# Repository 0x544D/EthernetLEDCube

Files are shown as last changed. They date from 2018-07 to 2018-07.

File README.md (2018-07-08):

# EthernetLEDCube
This project contains the PCB design files and software of the Ethernet controlled 6x6x6 LED Cube project. The project was successfully finished within the "System-on-Chip (SOC) + ARM Lab" course of TU Berlin.

Further information about the project can be found in the doc folder.

Project member:
* Tobias Minn
* Arne Salzwedel
* Julian Gog
* Max Thonagel

# Video of the result

Ethernet controlled 6x6x6 RGB LED-Cube - uncut (https://www.youtube.com/watch?v=e2JtOskrisI "Ethernet controlled 6x6x6 RGB LED-Cube - uncut")

# Pictures

Picture of the FPGA Board and the designed LED Cube PCB:

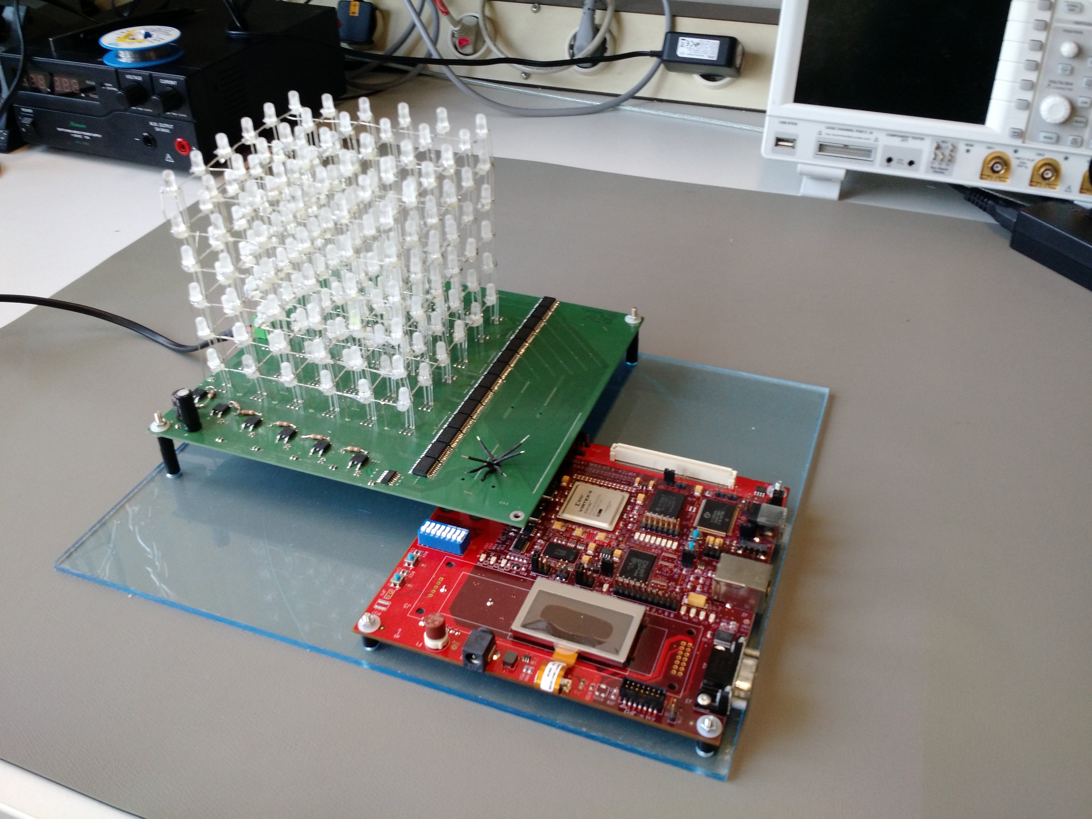
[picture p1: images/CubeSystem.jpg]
System


Animation on the Cube:
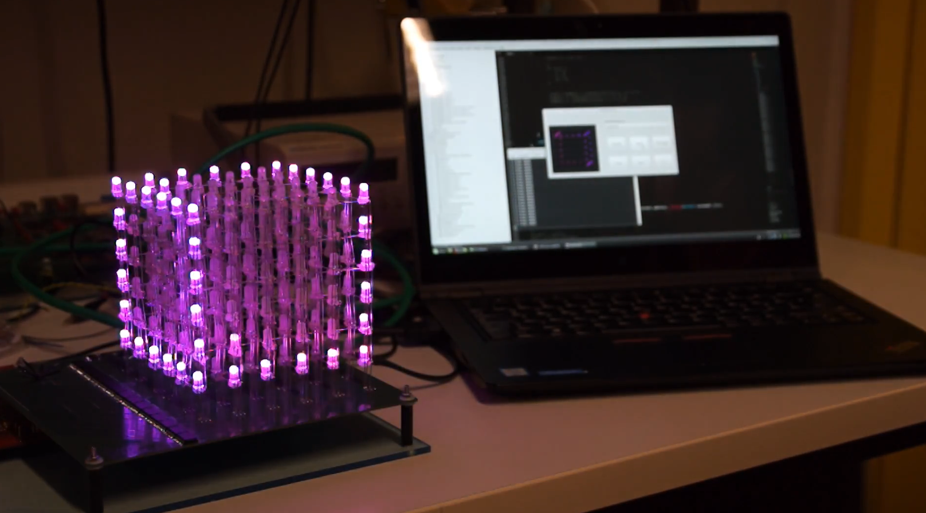
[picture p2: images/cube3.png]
Border Animation Borders


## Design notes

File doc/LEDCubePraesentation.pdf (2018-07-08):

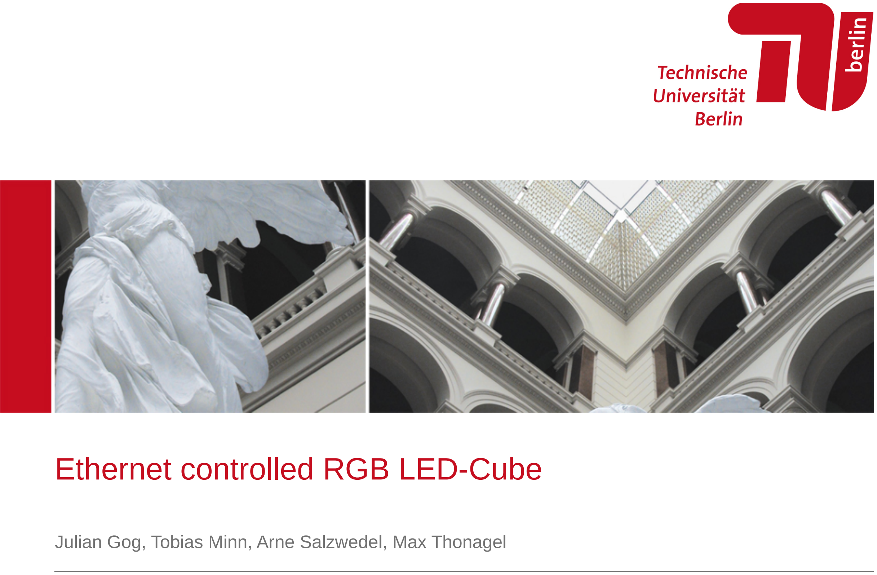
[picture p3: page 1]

# Ethernet controlled RGB LED-Cube

## Julian Gog, Tobias Minn, Arne Salzwedel, Max Thonagel

# Zielsetzung

# - 6x6x6 RGB LED-Cube

# - Ansteuerung per Ethernet

# - Verwendung von Raw-Ethernet-Frames (kein IP TCP/UDP)

Ethernet controlled RGB LED-Cube | Julian Gog, Tobias Minn, Arne Salzwedel, Max Thonagel

# Systemaufbau

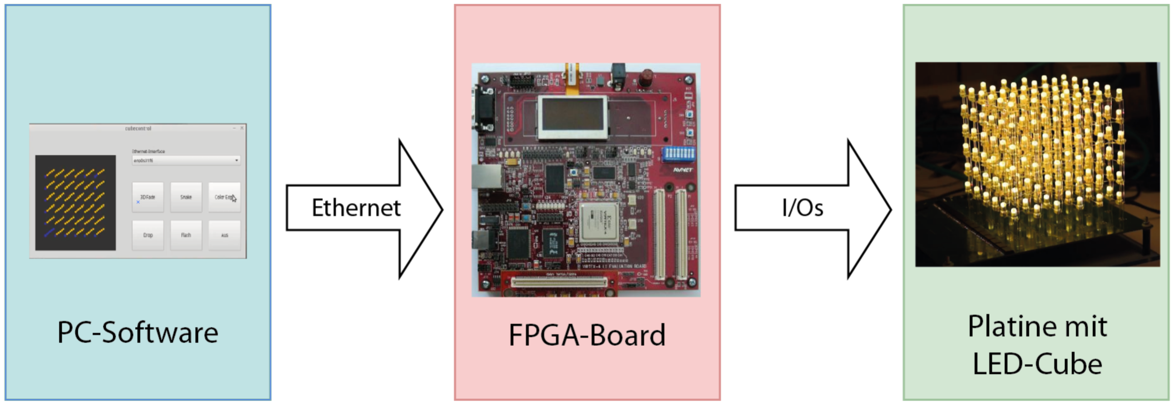
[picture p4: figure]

Bild-Quelle FPGA-Board: http://www.ue.eti.pg.gda.pl/fpgalab/spis_plytek/virtex4_av.jpg

# PC Software

# PC-Software - Aufgaben

# - Animation des Cubes mit verschieden Effekten/Mustern

# - GUI zur Interaktion mit Nutzer (Inbetriebnahme und Effekt-Auswahl)

# - Farbmischung und Dimmen

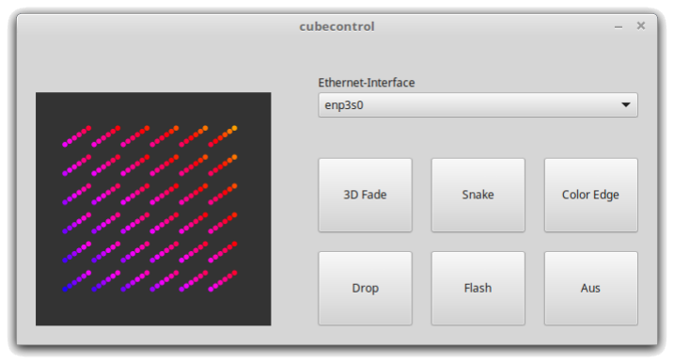
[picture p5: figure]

# durch Software-PWM

# - Codieren der Ethernet-Frames

# - Senden von Frames mit

# möglichst hoher Rate

# PC-Software - Funktionsweise

# - Bearbeitung in mehreren Threads:

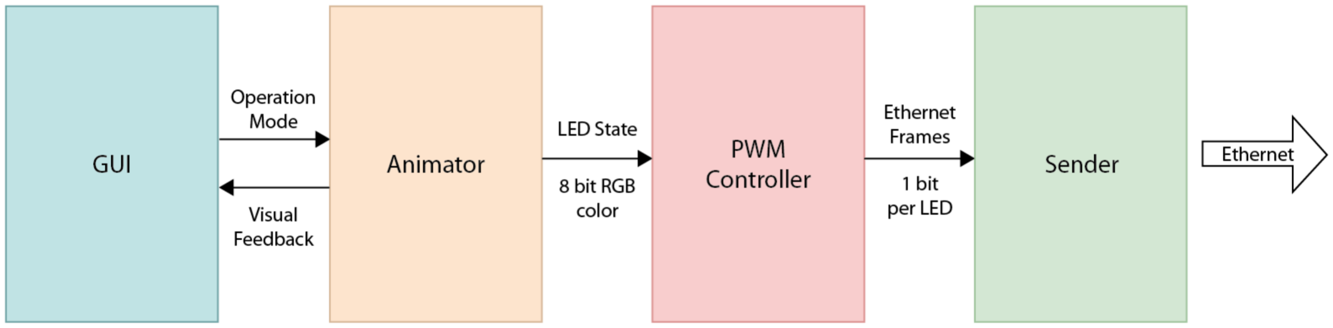
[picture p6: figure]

# System-on-Chip

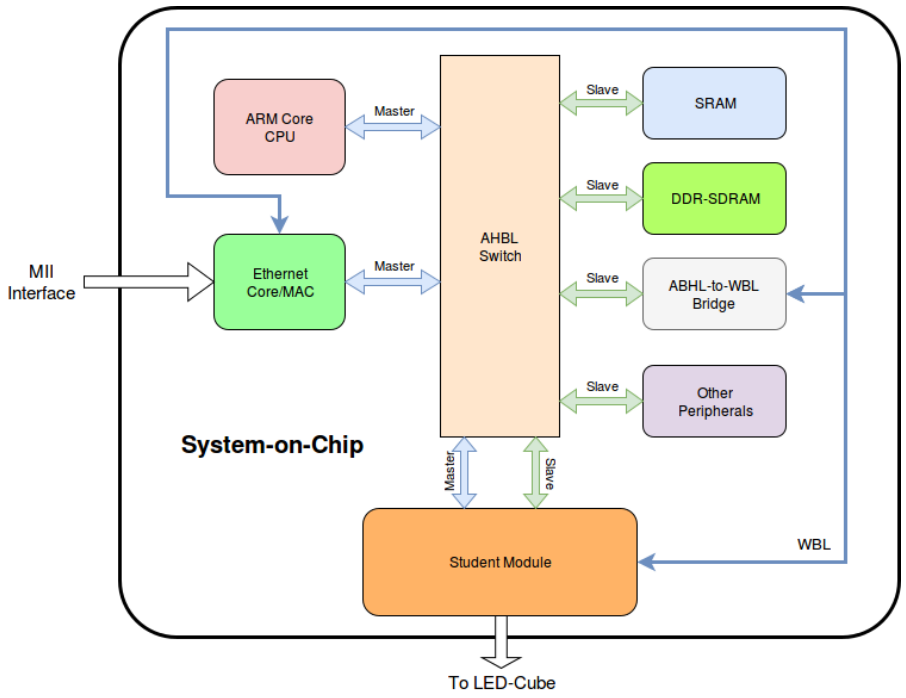
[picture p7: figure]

# Überblick

## - Standard Konfiguration des System-on-Chips des Armlabs

## - Ethernet Core/MAC wurde implementiert - Übernimmt Dekodierung des Ethernet Frames - Schreiben des Payloads in Speicher

## - Studentenmodul wurde implementiert - Enthält Ansteuerung der LED-Cube Hardware

# Ethernet Core/MAC

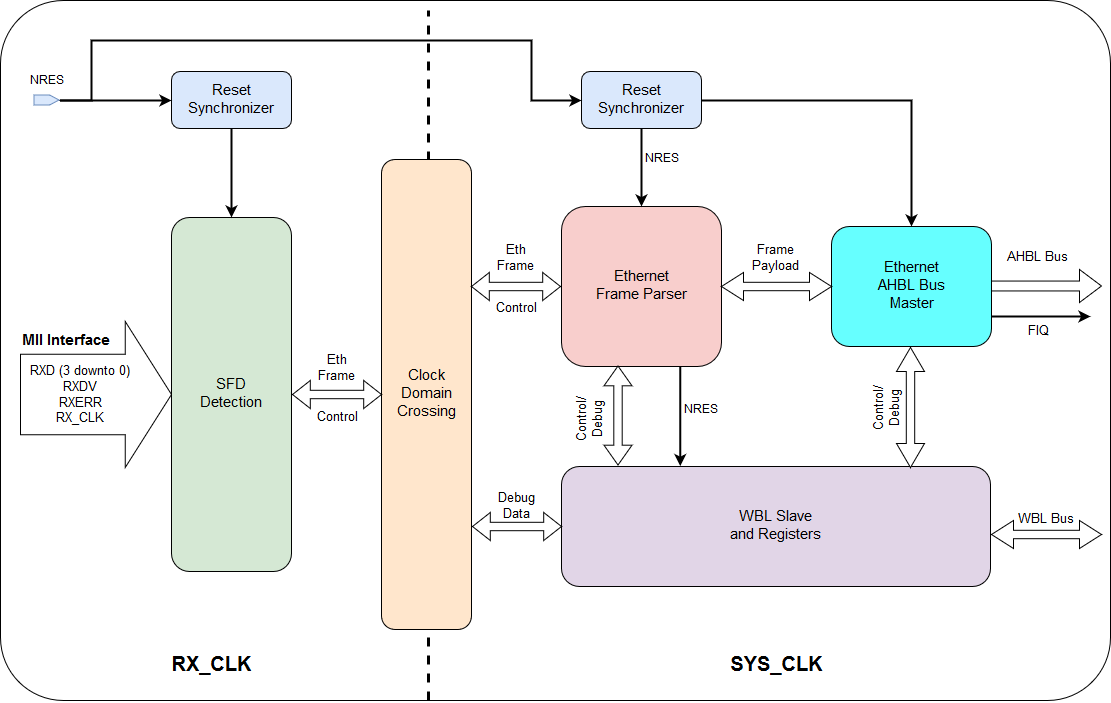
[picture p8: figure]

# SFD Erkennung

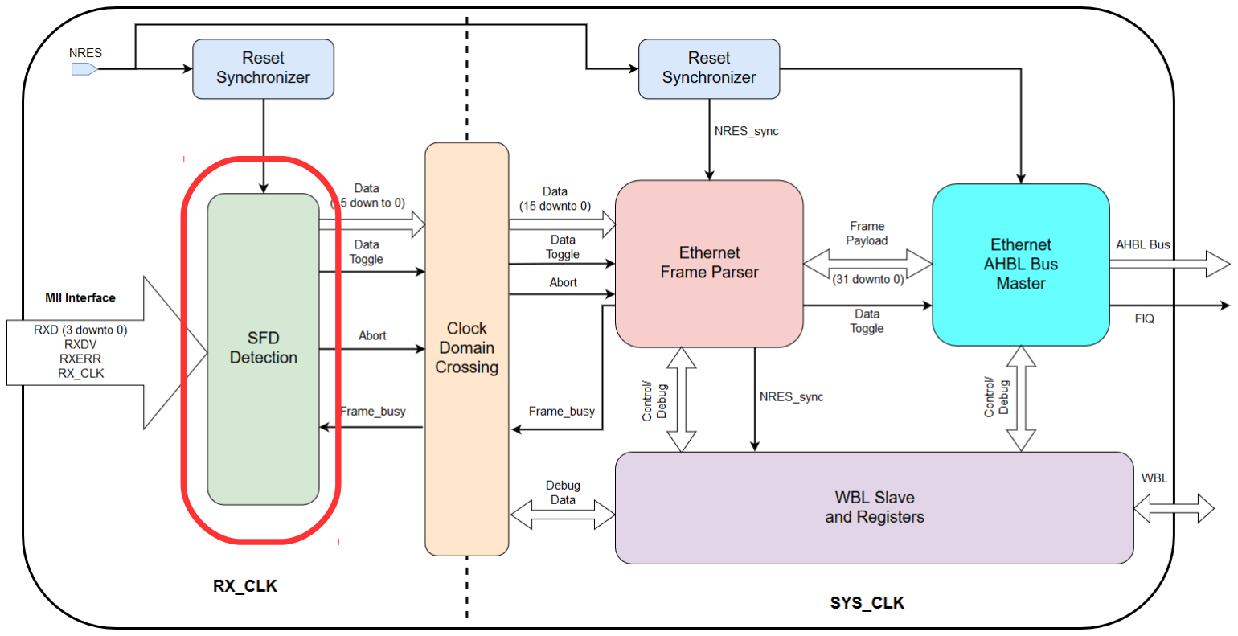
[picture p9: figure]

Preamble | Start of frame delimiter | MAC destination | MAC source | Ethertype or length | Payload | CRC
7 Bytes | 1 Byte | 6 Bytes | 6 Bytes | 2 Bytes | 46 – 1500 Bytes | 4 Bytes

## - SFD Erkennung verwirft die Preamble des Ethernet Frames bis SFD erkannt wird

## - Alle nachfolgenden Nibble werden in 16 Bit Blöcken zusammengefügt und an Parser weitergegeben

### Ethernet Frame

# Frame Parser

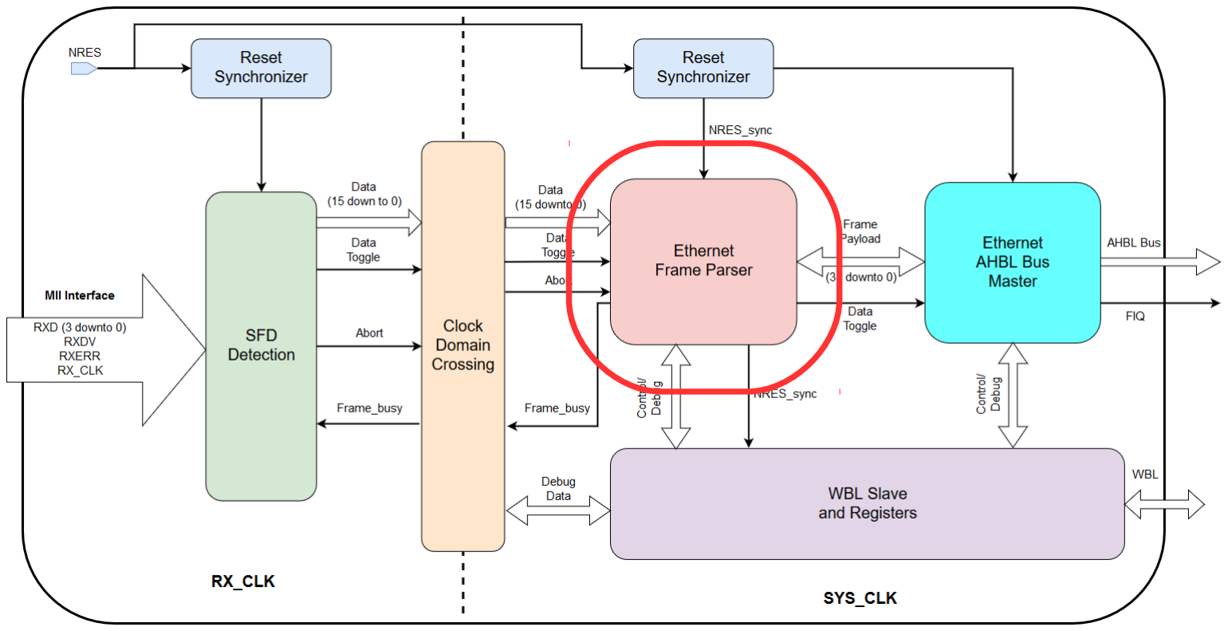
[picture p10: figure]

Preamble | Start of frame delimiter | MAC destination | MAC source | Ethertype or length | Payload | CRC
7 Bytes | 1 Byte | 6 Bytes | 6 Bytes | 2 Bytes | 46 – 1500 Bytes | 4 Bytes Ethernet Frame

## - Parser dekodiert einzelne Felder des Ethernet Frames

## - Prüft ob Ziel MAC Adresse stimmt

## - Gibt Payload und Länge an AHBL Bus Master weiter

# AHBL Bus Master

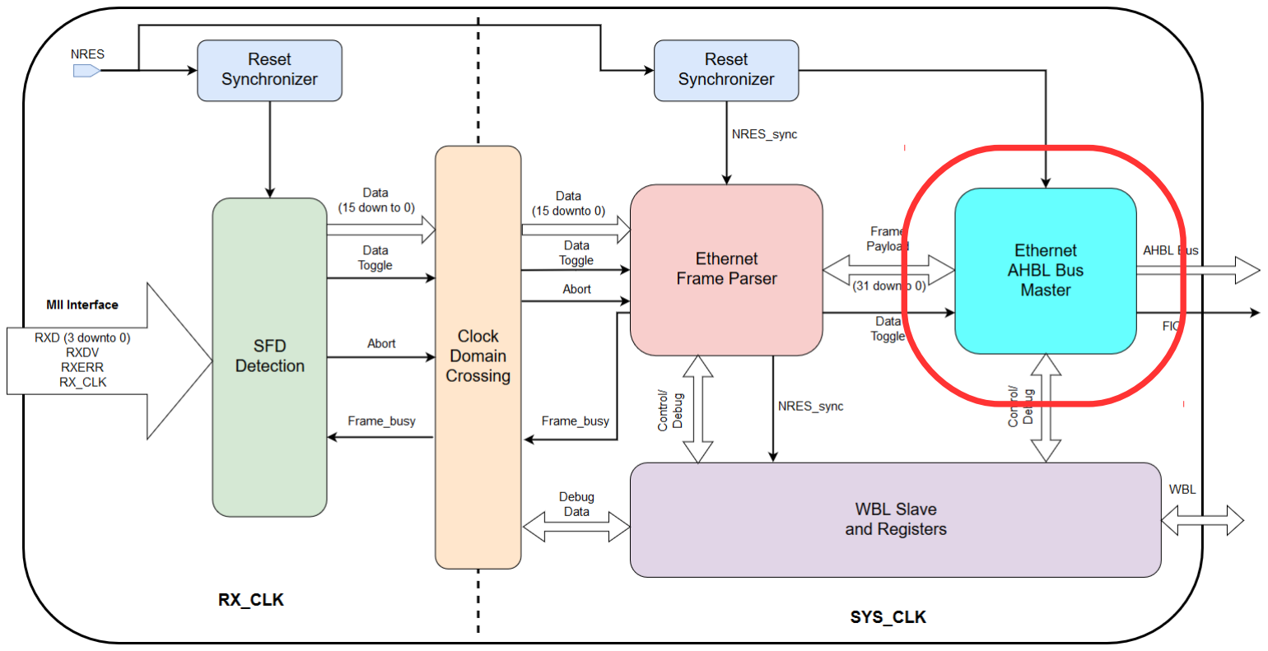
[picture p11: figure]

Preamble | Start of frame delimiter | MAC destination | MAC source | Ethertype or length | Payload | CRC
7 Bytes | 1 Byte | 6 Bytes | 6 Bytes | 2 Bytes | 46 – 1500 Bytes | 4 Bytes Ethernet Frame

## - Nimmt Daten in 32 Bit Blöcken vom Parser entgegen

## - Schreibt die ankommenden Daten an eine konfigurierbare Speicheradresse

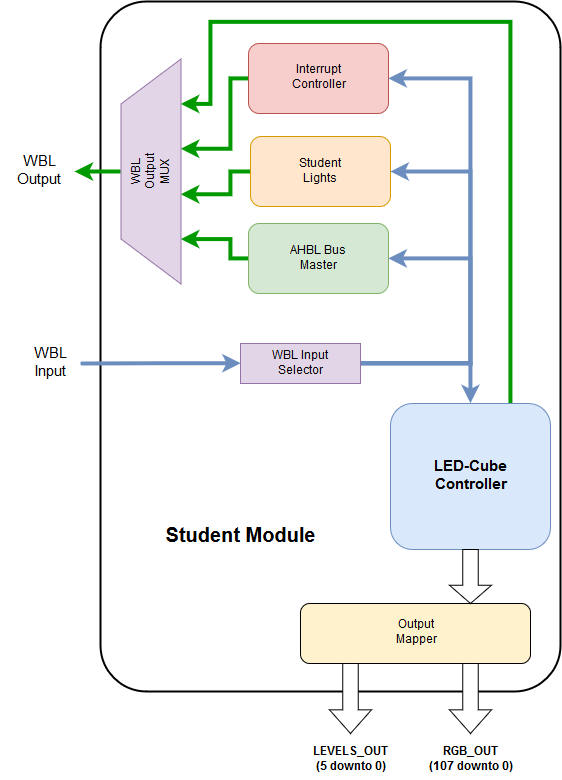
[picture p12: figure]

# LED Cube Controller

## - LED-Cube Controller übernimmt Ansteuerung des LED-Cubes – Multiplexing der LED-Ebenen – Ansteuerung der einzelnen LED Pins

## - Controller hat Register für jede LED des Cubes - Daten werden über WBL Interface in Register geschrieben - Umschalten der Ebenen auf Ausgabe Port erfolgt über MUX

# Hardware

# Hardware Features

# - 6x6x6 = 216 RGB LEDs

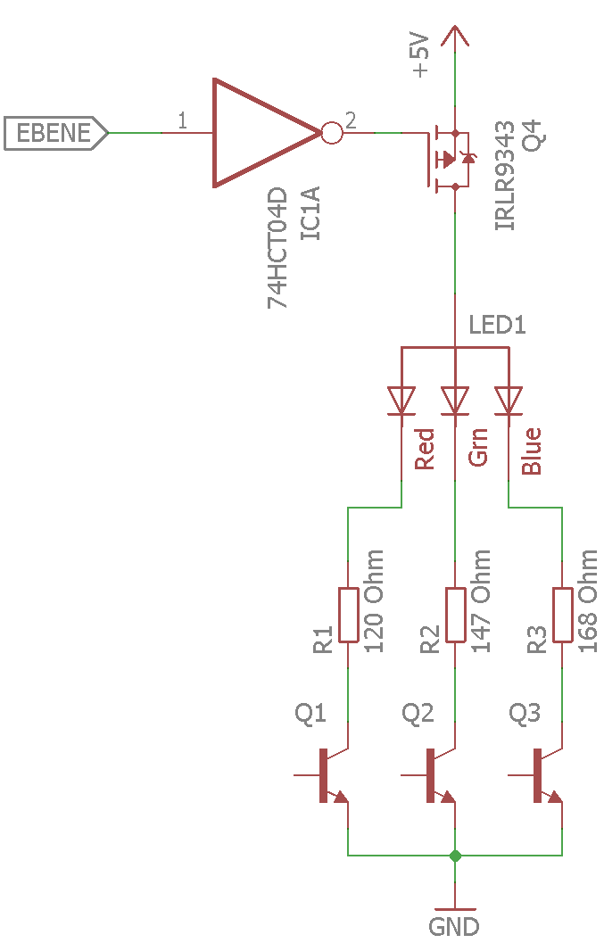
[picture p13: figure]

# - Common anode LEDs

# - Nacheinander angesteuerte

# Ebenen

# - LEDs sind nie gleichzeitig an

# - Menschliches Auge ist zu träge

# - Steuerung der LEDs via

# Darlington Arrays (ULN2803)

# - Aufbau:

…

…

…

# Demo

# Demo Video

## https://www.youtube.com/watch?v=e2JtOskrisI

# Backup Slides

# SFD Erkennung

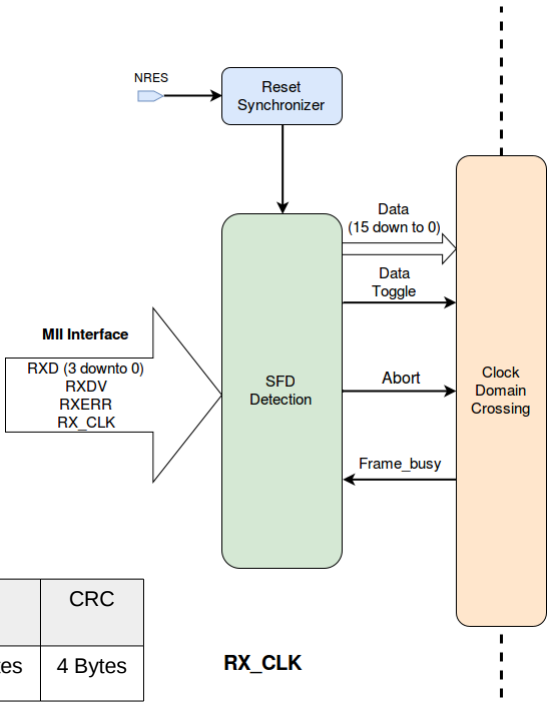
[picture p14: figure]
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

- Start of frame delimiter Erkennung nimmt Daten vom Ethernet PHY entgegen - Verwirft die Preamble des Ethernet Frames bis SFD erkannt wird - Alle nachfolgenden Nibble werden in 16 Bit Blöcken zusammengefügt - CDC von 16 Bit Blöcken in die System Clock Domain - Zusätzliche Steuersignale werden synchronisiert (Data Toggle, Abort, Frame)

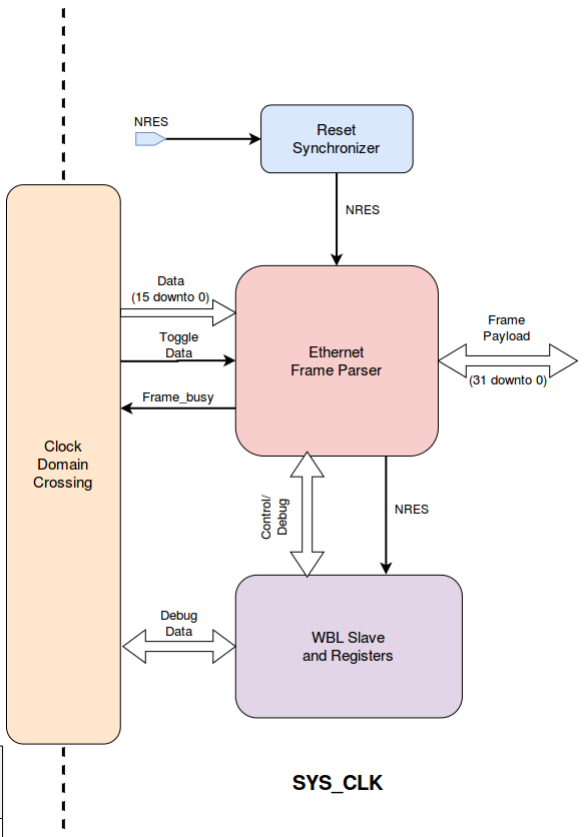
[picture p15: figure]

# Ethernet Parser

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

## - Dekodiert die ankommenden 16 Bit Blöcke

- Prüft ob ankommende Pakete für FPGA bestimmt sind,

## anhand der Ziel MAC-Adresse (konfigurierbar) - Analysiert Länge des Pakets und bereitet Datentransfer in den Speicher vor - Gibt die ankommenden Daten an AHBL Bus Master weiter - CRC wird entgegen genommen, aber momentan noch nicht geprüft

# Ethernet Frame Decode

## - SFD Erkennung verwirft die Preamble des Ethernet Frames bis SFD erkannt wird

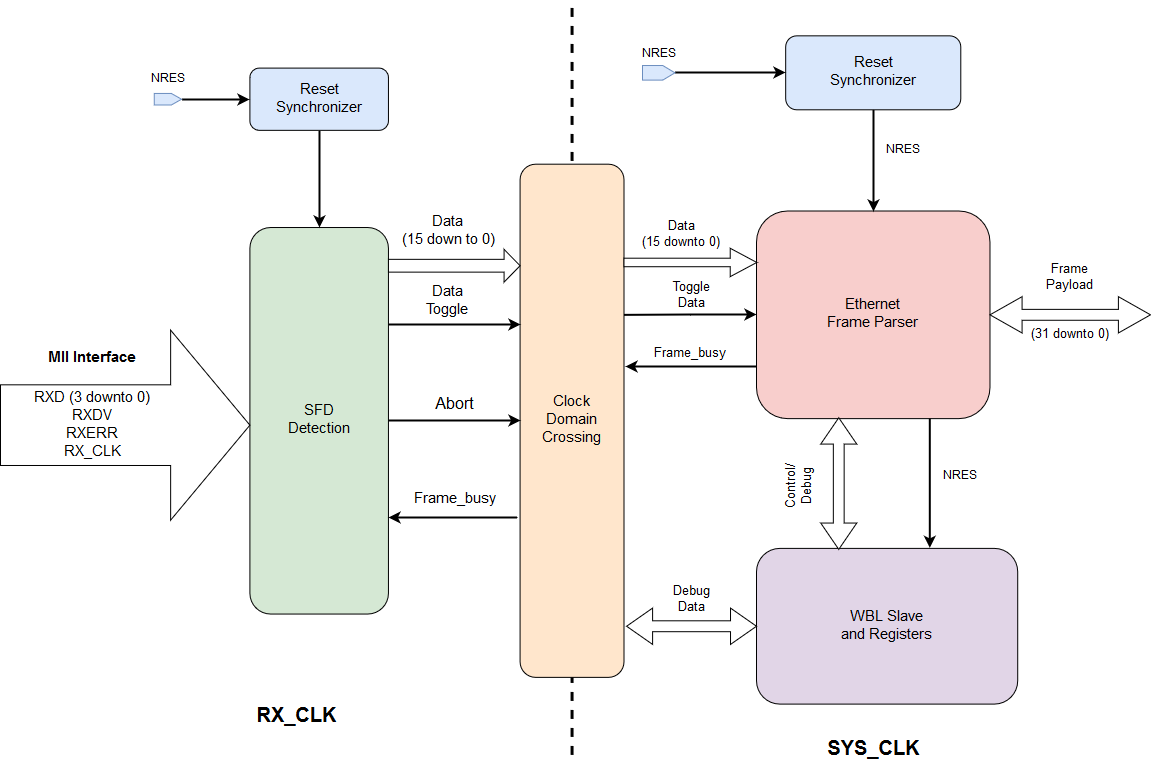
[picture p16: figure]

## - Alle nachfolgenden Nibble werden in 16 Bit Blöcken zusammengefügt - Parser dekodiert einzelne Felder des Ethernet Frames - AHBL Master schreibt Payload in den Speicher

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

# Ethernet AHBL Bus Master

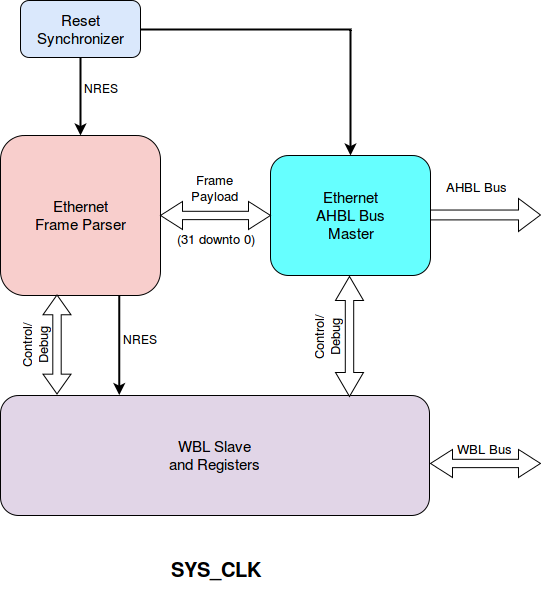
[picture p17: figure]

## - Nimmt Daten in 32 Bit Blöcken vom Parser entgegen

## - Schreibt die ankommenden Daten an eine konfigurierbare Speicheradresse (über WBL Slave) - Daten werden über AHBL Interface geschrieben

# MII Übertragung

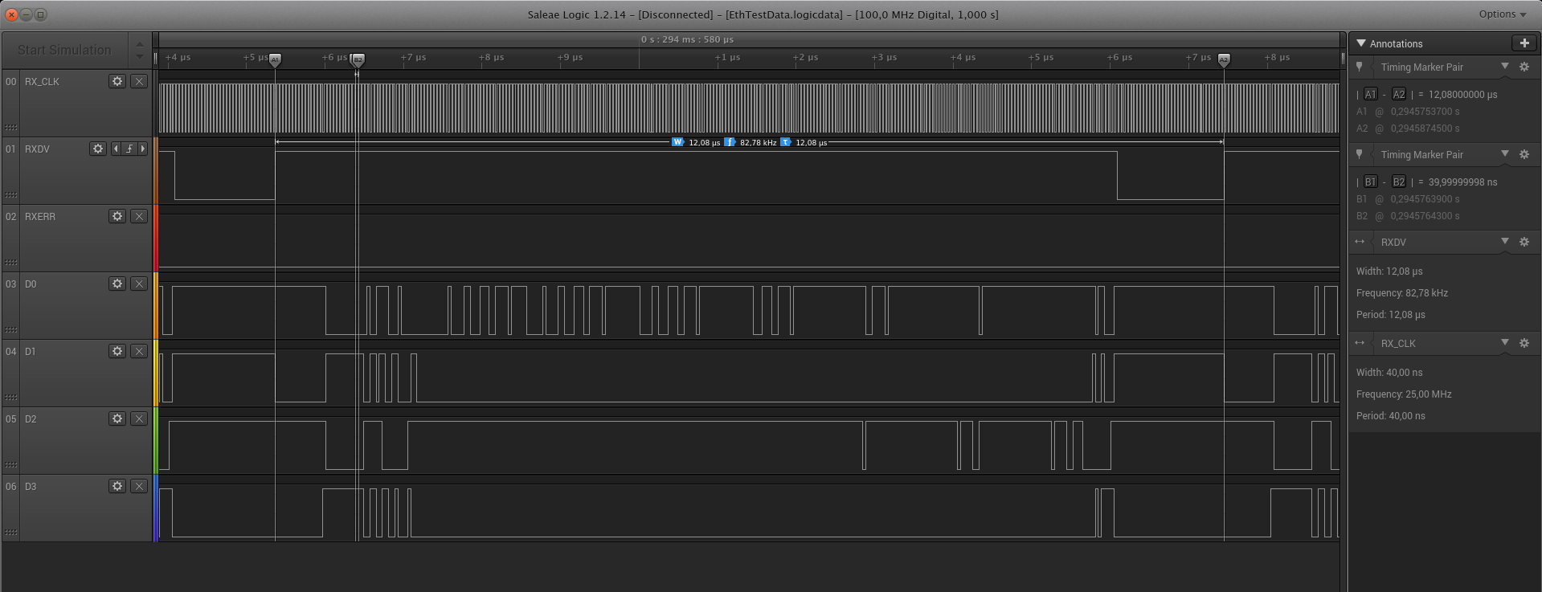
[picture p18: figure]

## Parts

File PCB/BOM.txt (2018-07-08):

Segor:
======

- ARK 2-Lift (24A)	0,40€
- ARK 2	(8A)		0,25€

Digikey:
========

- 6 x IRLR9343TRPBFTR-ND 	0,79€
- 6 x 1727-4692-1-ND		0,13€

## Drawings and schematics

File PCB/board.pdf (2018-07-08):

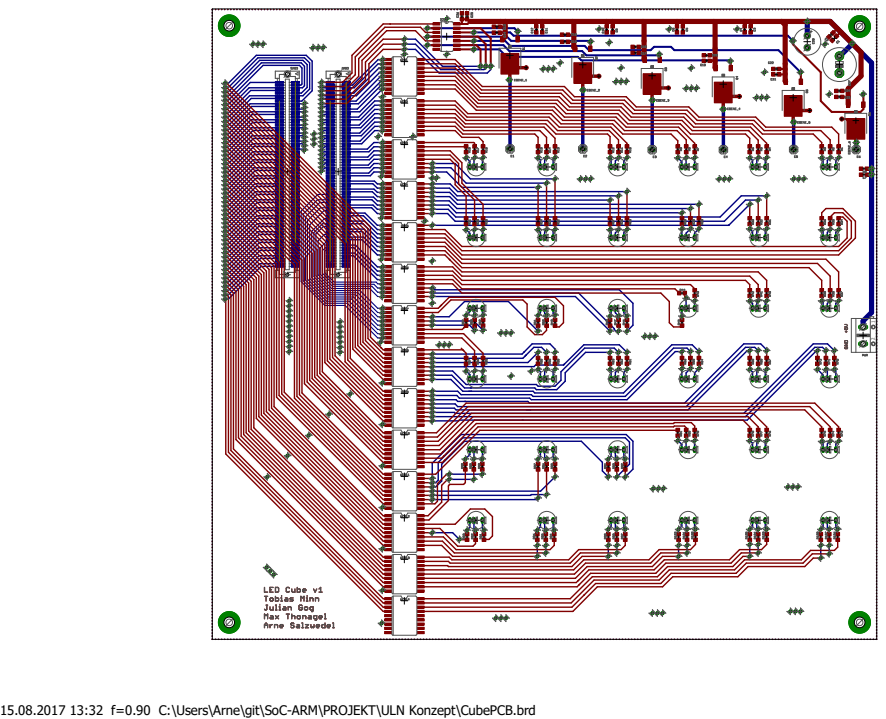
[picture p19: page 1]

15.08.2017 13:32 f=0.90 C:\Users\Arne\git\SoC-ARM\PROJEKT\ULN Konzept\CubePCB.brd

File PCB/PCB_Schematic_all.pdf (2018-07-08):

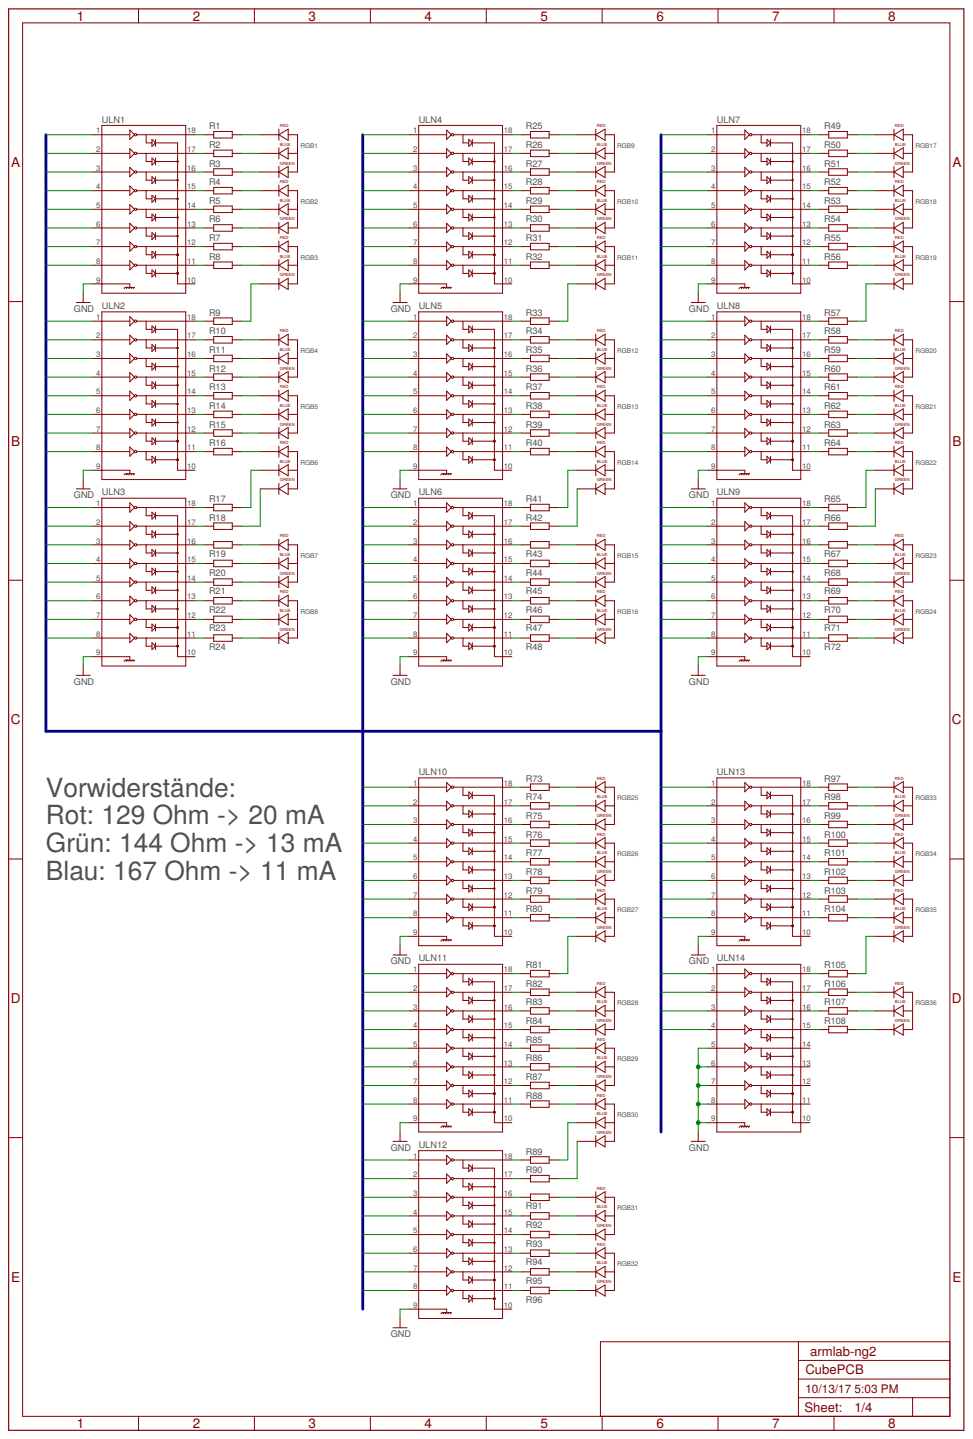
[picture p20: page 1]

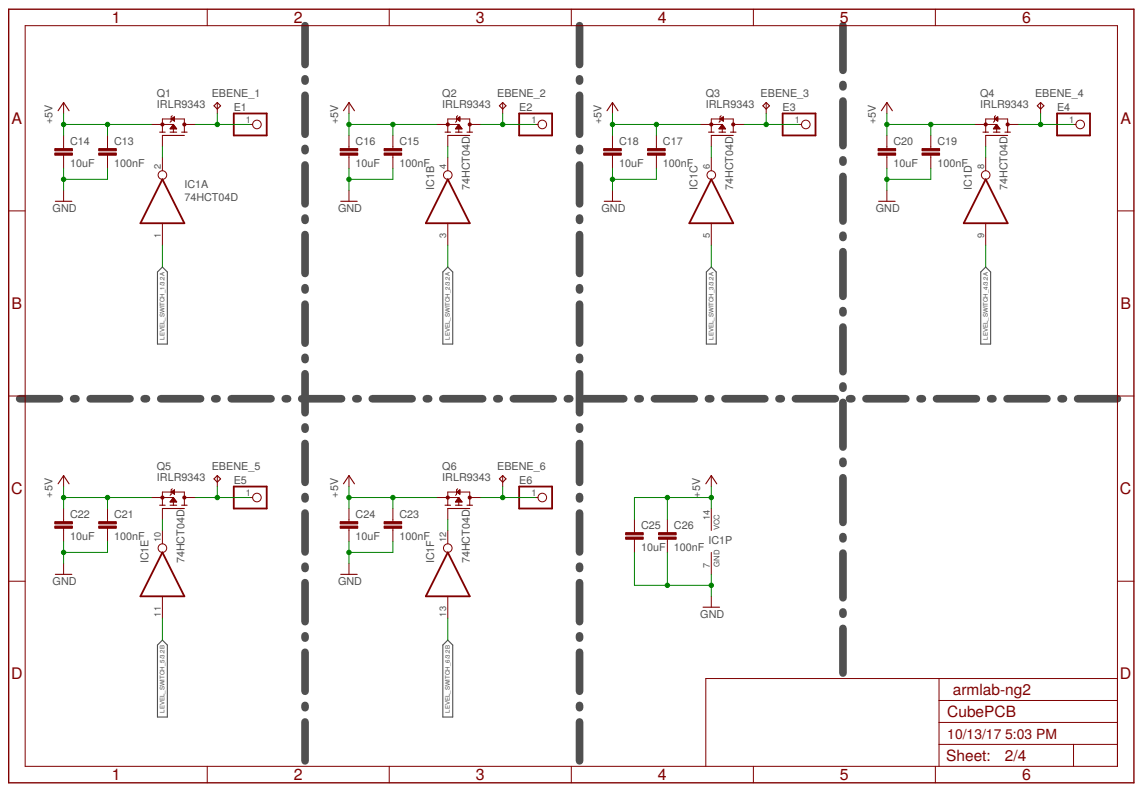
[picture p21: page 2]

EBENE_1 EBENE_2 EBENE_3 | EBENE_4

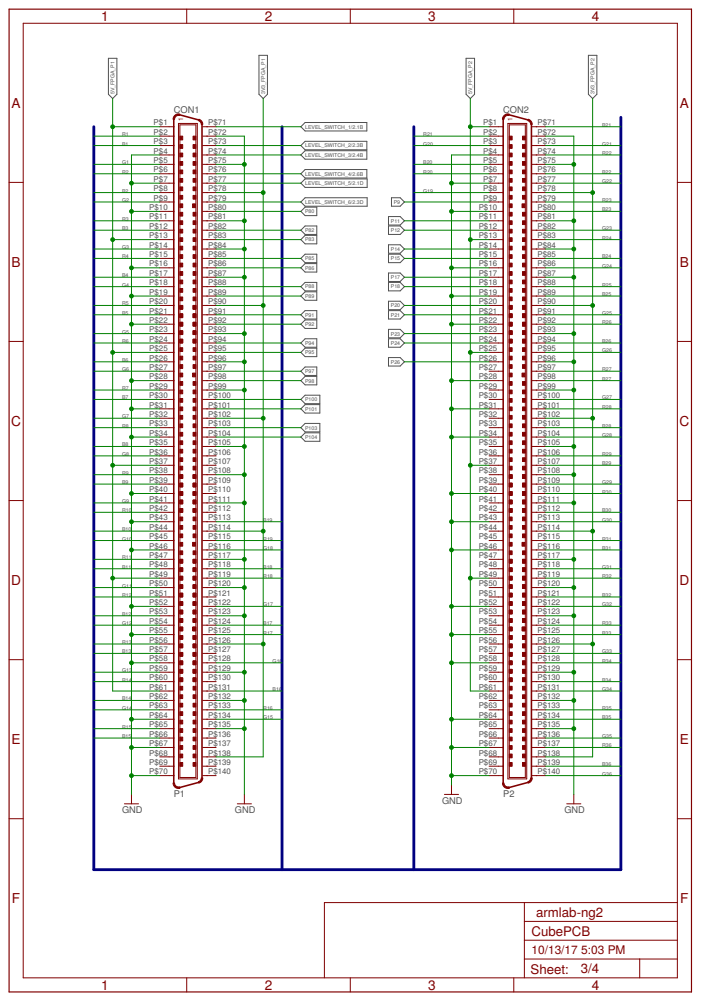
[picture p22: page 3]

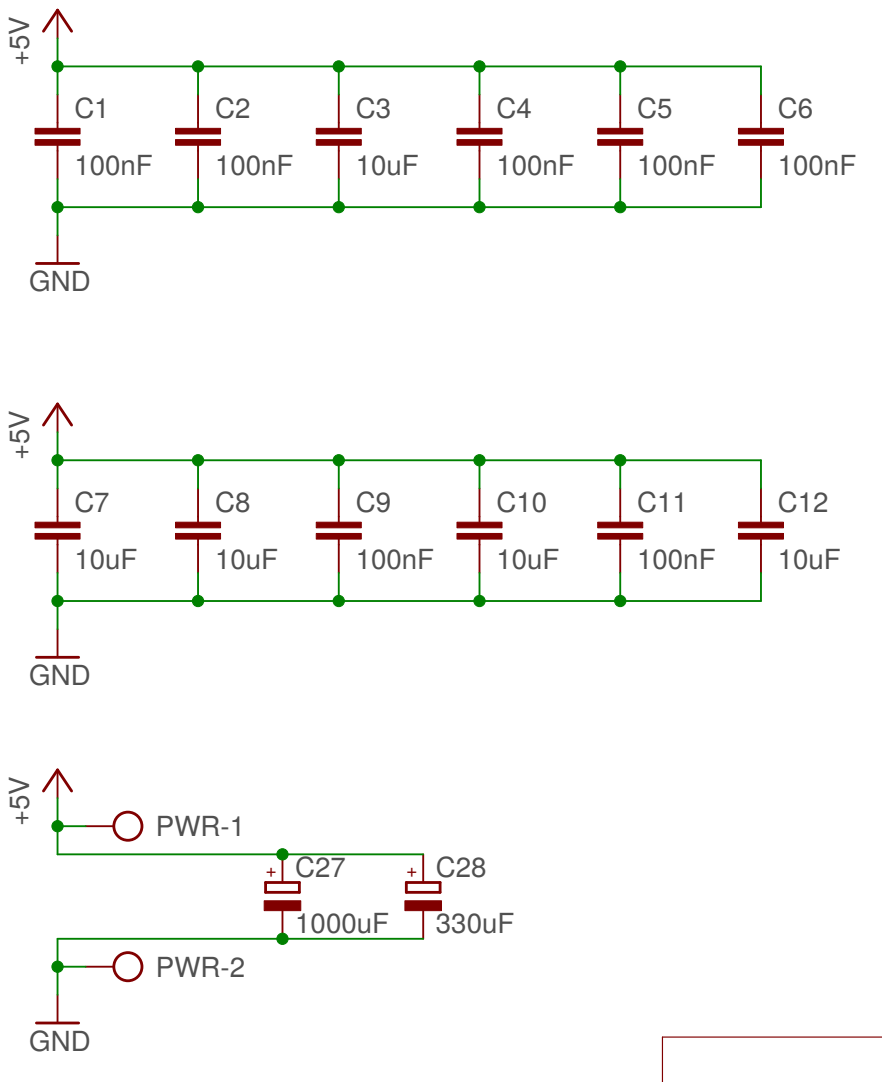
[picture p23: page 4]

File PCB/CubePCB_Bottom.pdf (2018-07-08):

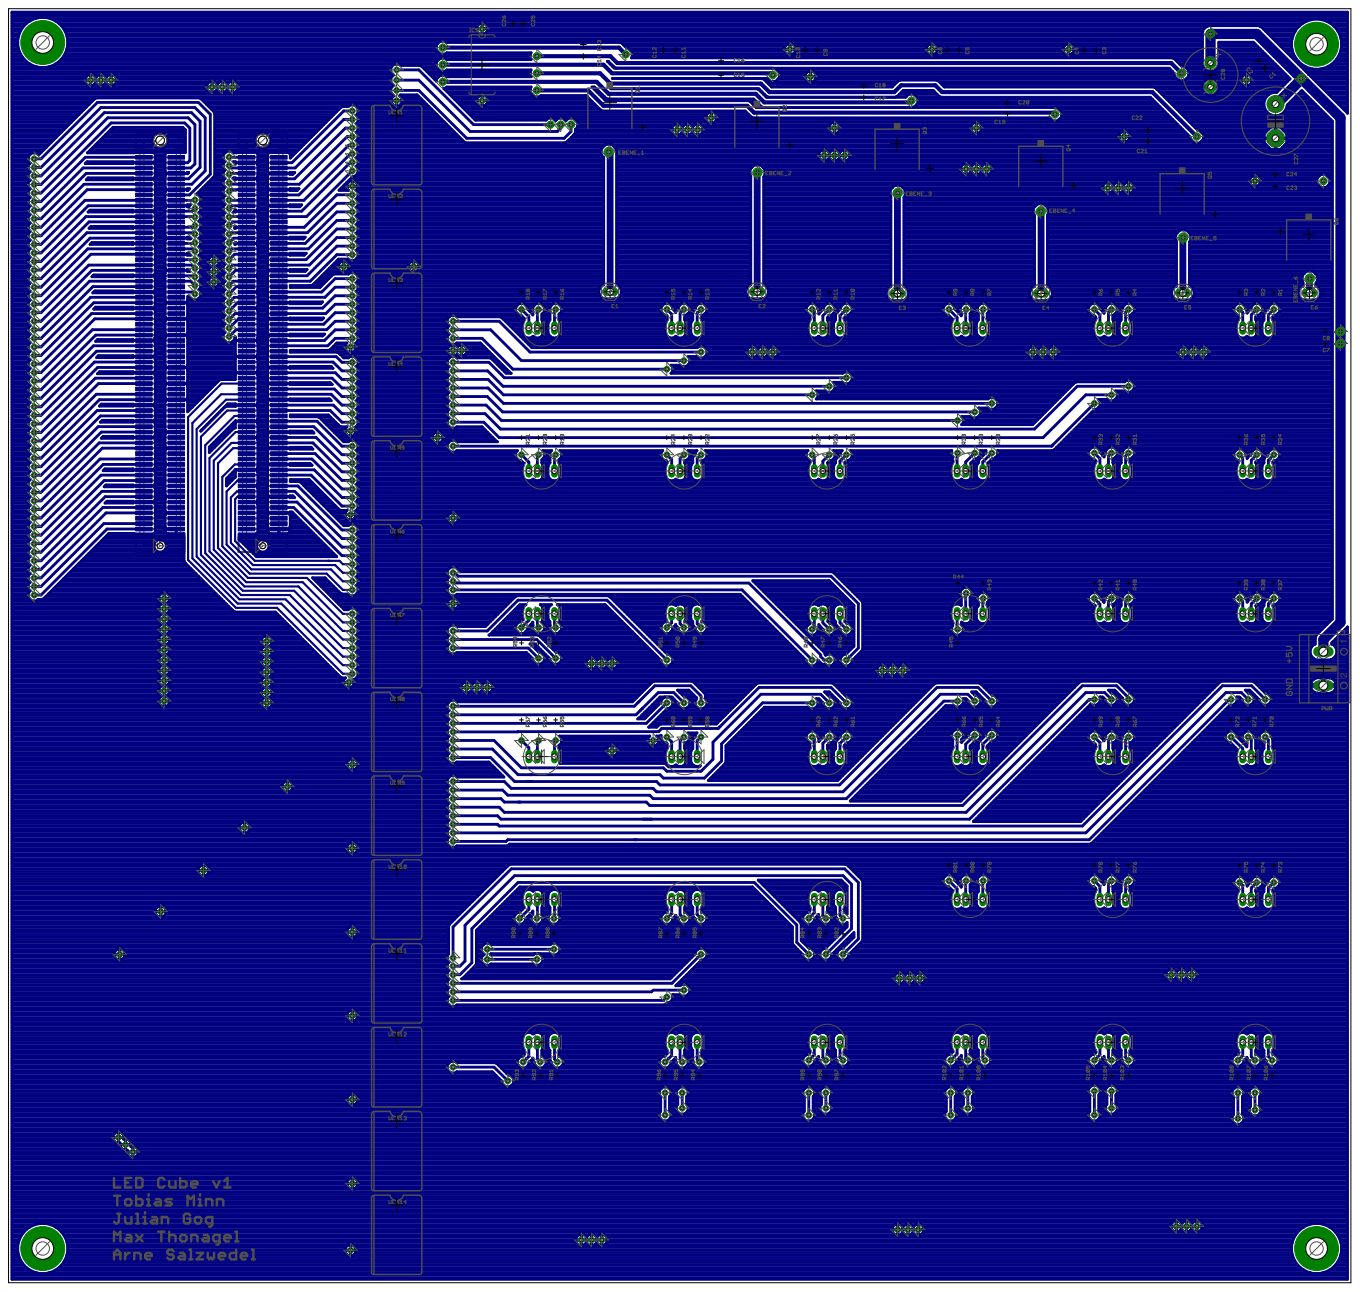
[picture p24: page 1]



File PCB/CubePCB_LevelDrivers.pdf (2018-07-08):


EBENE_1 EBENE_2 EBENE_3 | EBENE_4


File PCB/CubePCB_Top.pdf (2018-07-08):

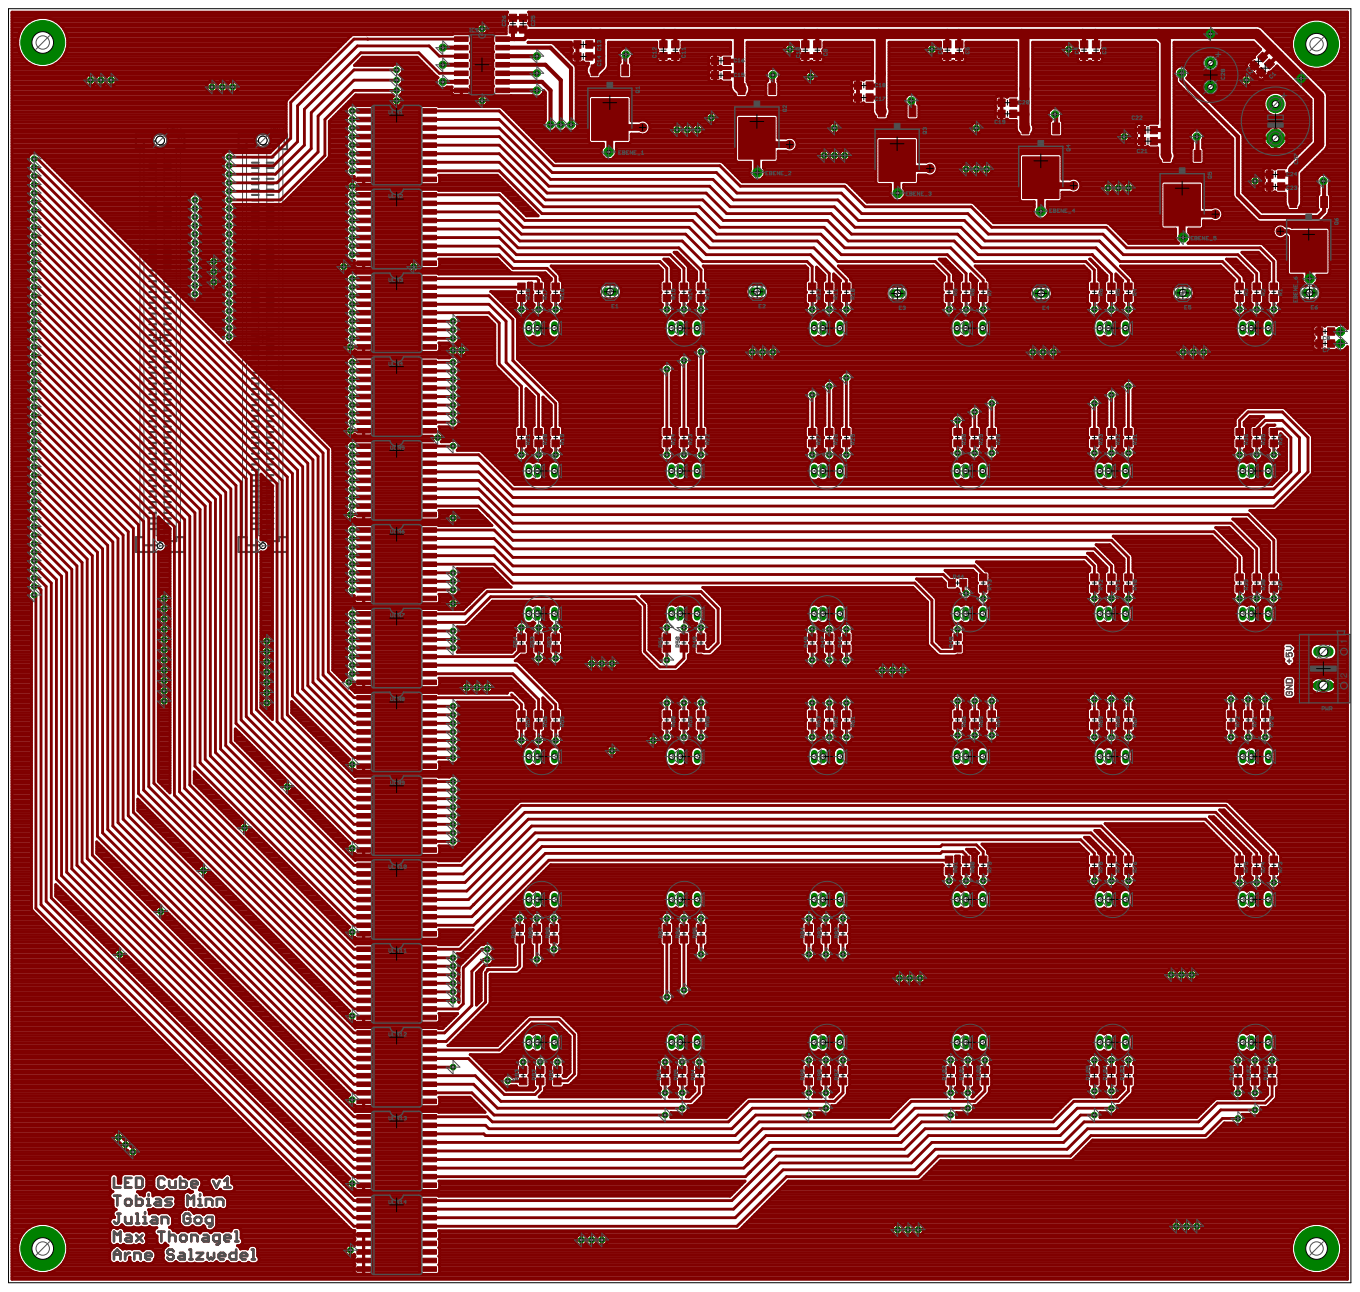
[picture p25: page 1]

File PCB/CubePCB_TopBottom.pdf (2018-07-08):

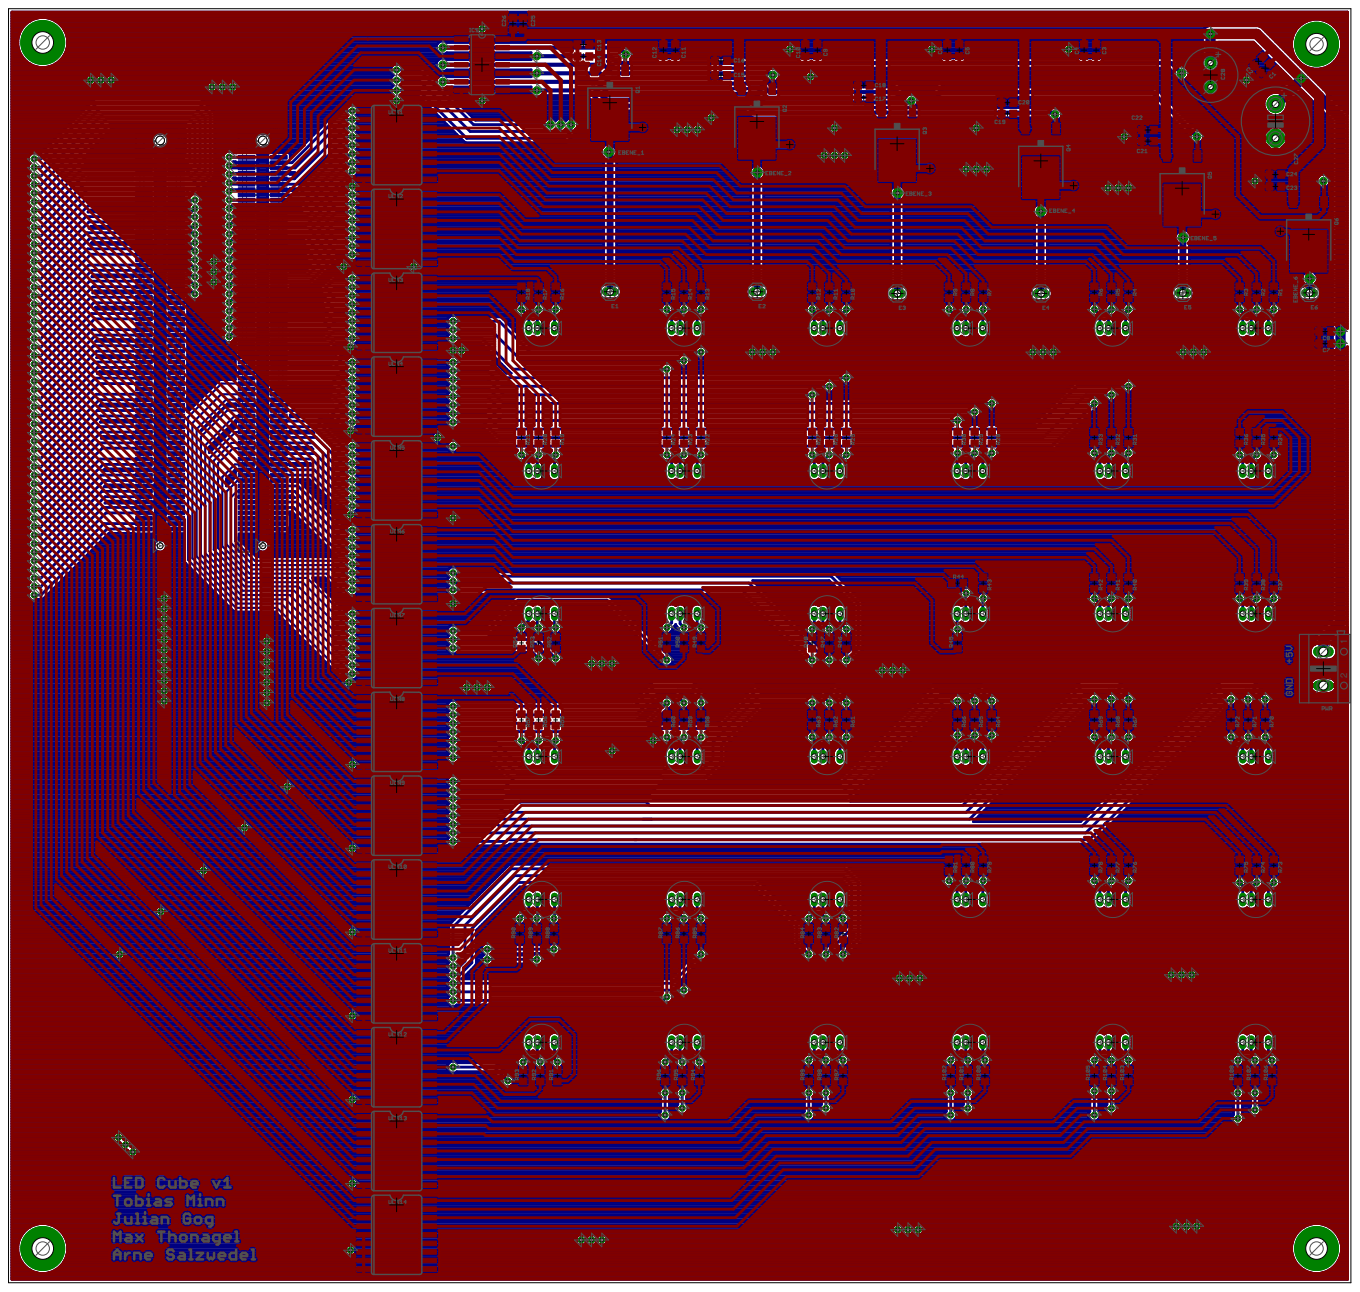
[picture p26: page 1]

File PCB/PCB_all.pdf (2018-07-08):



EBENE_1 EBENE_2 EBENE_3 | EBENE_4









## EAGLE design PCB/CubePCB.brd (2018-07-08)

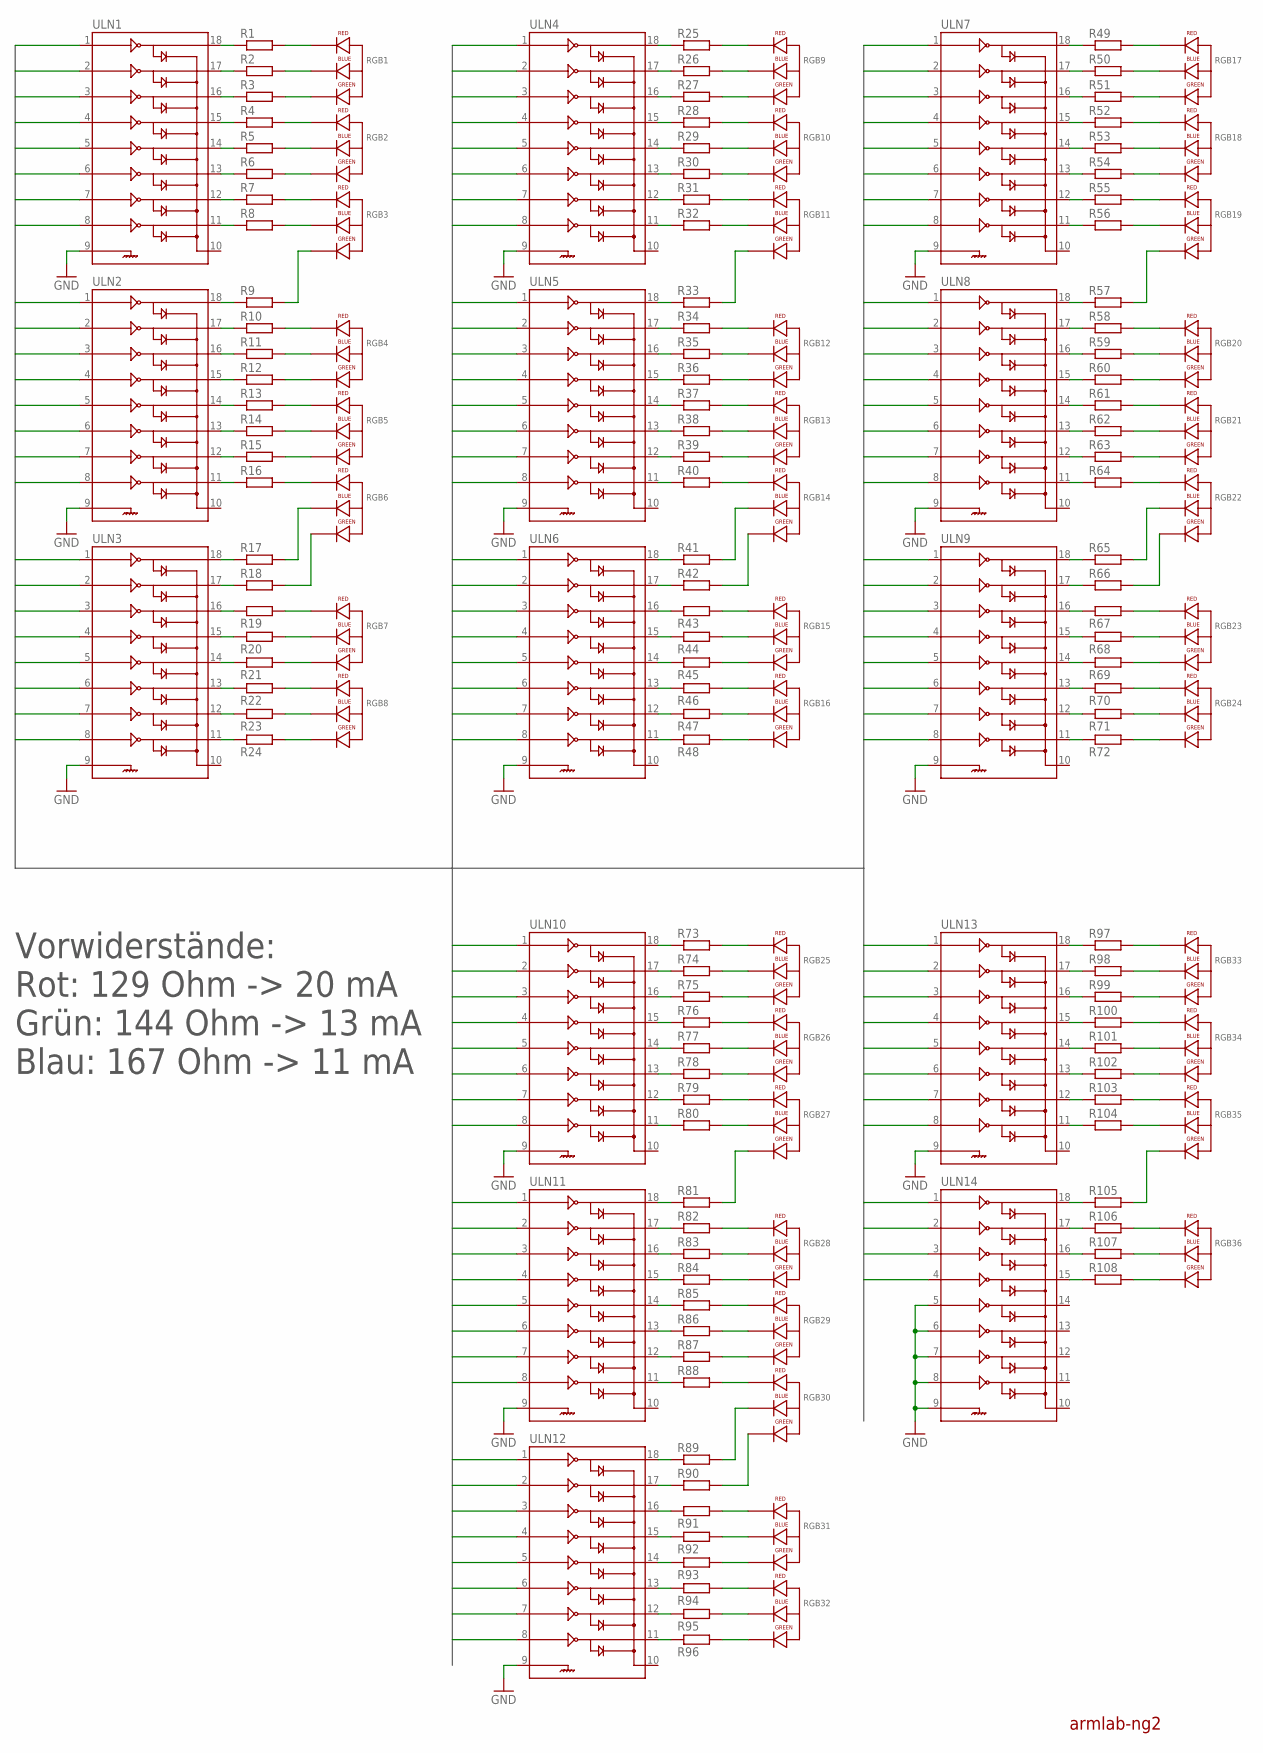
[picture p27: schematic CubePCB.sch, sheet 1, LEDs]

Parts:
R1, R2, R3, R4, R5, R6, R7, R8, R9, R10, R11, R12, R13, R14, R15, R16, R17, R18, R19, R20, R21, R22, R23, R24, R25, R26, R27, R28, R29, R30, R31, R32, R33, R34, R35, R36, R37, R38, R39, R40, R41, R42, R43, R44, R45, R46, R47, R48, R49, R50, R51, R52, R53, R54, R55, R56, R57, R58, R59, R60, R61, R62, R63, R64, R65, R66, R67, R68, R69, R70, R71, R72, R73, R74, R75, R76, R77, R78, R79, R80, R81, R82, R83, R84, R85, R86, R87, R88, R89, R90, R91, R92, R93, R94, R95, R96, R97, R98, R99, R100, R101, R102, R103, R104, R105, R106, R107, R108: R-EU_R0603; R0603
RGB1, RGB2, RGB3, RGB4, RGB5, RGB6, RGB7, RGB8, RGB9, RGB10, RGB11, RGB12, RGB13, RGB14, RGB15, RGB16, RGB17, RGB18, RGB19, RGB20, RGB21, RGB22, RGB23, RGB24, RGB25, RGB26, RGB27, RGB28, RGB29, RGB30, RGB31, RGB32, RGB33, RGB34, RGB35, RGB36: LED-RGB-CA-ANODE-SPLIT; LED-RGB-WO-ANODE
ULN1, ULN2, ULN3, ULN4, ULN5, ULN6, ULN7, ULN8, ULN9, ULN10, ULN11, ULN12, ULN13, ULN14: ULN2803SOICW; SO18L

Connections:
B1: ULN1.2; also elsewhere on the board
B2: ULN1.5; also elsewhere on the board
B3: ULN1.8; also elsewhere on the board
B4: ULN2.3; also elsewhere on the board
B5: ULN2.6; also elsewhere on the board
B6: ULN3.1; also elsewhere on the board
B7: ULN3.4; also elsewhere on the board
B8: ULN3.7; also elsewhere on the board
B9: ULN4.2; also elsewhere on the board
B10: ULN4.5; also elsewhere on the board
B11: ULN4.8; also elsewhere on the board
B12: ULN5.3; also elsewhere on the board
B13: ULN5.6; also elsewhere on the board
B14: ULN6.1; also elsewhere on the board
B15: ULN6.4; also elsewhere on the board
B16: ULN6.7; also elsewhere on the board
B17: ULN7.2; also elsewhere on the board
B18: ULN7.5; also elsewhere on the board
B19: ULN7.8; also elsewhere on the board
B20: ULN8.3; also elsewhere on the board
B21: ULN8.6; also elsewhere on the board
B22: ULN9.1; also elsewhere on the board
B23: ULN9.4; also elsewhere on the board
B24: ULN9.7; also elsewhere on the board
B25: ULN10.2; also elsewhere on the board
B26: ULN10.5; also elsewhere on the board
B27: ULN10.8; also elsewhere on the board
B28: ULN11.3; also elsewhere on the board
B29: ULN11.6; also elsewhere on the board
B30: ULN12.1; also elsewhere on the board
B31: ULN12.4; also elsewhere on the board
B32: ULN12.7; also elsewhere on the board
B33: ULN13.2; also elsewhere on the board
B34: ULN13.5; also elsewhere on the board
B35: ULN13.8; also elsewhere on the board
B36: ULN14.3; also elsewhere on the board
G1: ULN1.3; also elsewhere on the board
G2: ULN1.6; also elsewhere on the board
G3: ULN2.1; also elsewhere on the board
G4: ULN2.4; also elsewhere on the board
G5: ULN2.7; also elsewhere on the board
G6: ULN3.2; also elsewhere on the board
G7: ULN3.5; also elsewhere on the board
G8: ULN3.8; also elsewhere on the board
G9: ULN4.3; also elsewhere on the board
G10: ULN4.6; also elsewhere on the board
G11: ULN5.1; also elsewhere on the board
G12: ULN5.4; also elsewhere on the board
G13: ULN5.7; also elsewhere on the board
G14: ULN6.2; also elsewhere on the board
G15: ULN6.5; also elsewhere on the board
G16: ULN6.8; also elsewhere on the board
G17: ULN7.3; also elsewhere on the board
G18: ULN7.6; also elsewhere on the board
G19: ULN8.1; also elsewhere on the board
G20: ULN8.4; also elsewhere on the board
G21: ULN8.7; also elsewhere on the board
G22: ULN9.2; also elsewhere on the board
G23: ULN9.5; also elsewhere on the board
G24: ULN9.8; also elsewhere on the board
G25: ULN10.3; also elsewhere on the board
G26: ULN10.6; also elsewhere on the board
G27: ULN11.1; also elsewhere on the board
G28: ULN11.4; also elsewhere on the board
G29: ULN11.7; also elsewhere on the board
G30: ULN12.2; also elsewhere on the board
G31: ULN12.5; also elsewhere on the board
G32: ULN12.8; also elsewhere on the board
G33: ULN13.3; also elsewhere on the board
G34: ULN13.6; also elsewhere on the board
G35: ULN14.1; also elsewhere on the board
G36: ULN14.4; also elsewhere on the board
GND: ULN1.9, ULN2.9, ULN3.9, ULN4.9, ULN5.9, ULN6.9, ULN7.9, ULN8.9, ULN9.9, ULN10.9, ULN11.9, ULN12.9, ULN13.9, ULN14.5, ULN14.6, ULN14.7, ULN14.8, ULN14.9; also elsewhere on the board
unnamed: R1.1, ULN1.18
unnamed: R2.1, ULN1.17
unnamed: R3.1, ULN1.16
unnamed: R3.2, RGB1.G (GREEN_CATHODE)
unnamed: R2.2, RGB1.B (BLUE_CATHODE)
unnamed: R1.2, RGB1.R (RED_CATHODE)
unnamed: R4.1, ULN1.15
unnamed: R5.1, ULN1.14
unnamed: R6.1, ULN1.13
unnamed: R7.1, ULN1.12
unnamed: R6.2, RGB2.G (GREEN_CATHODE)
unnamed: R5.2, RGB2.B (BLUE_CATHODE)
unnamed: R4.2, RGB2.R (RED_CATHODE)
unnamed: R8.1, ULN1.11
unnamed: R19.1, ULN3.16
unnamed: R20.1, ULN3.15
unnamed: R9.2, RGB3.G (GREEN_CATHODE)
unnamed: R8.2, RGB3.B (BLUE_CATHODE)
unnamed: R7.2, RGB3.R (RED_CATHODE)
unnamed: R21.1, ULN3.14
unnamed: R22.1, ULN3.13
unnamed: R23.1, ULN3.12
unnamed: R12.2, RGB4.G (GREEN_CATHODE)
unnamed: R11.2, RGB4.B (BLUE_CATHODE)
unnamed: R10.2, RGB4.R (RED_CATHODE)
unnamed: R24.1, ULN3.11
unnamed: R27.2, RGB9.G (GREEN_CATHODE)
unnamed: R26.2, RGB9.B (BLUE_CATHODE)
unnamed: R15.2, RGB5.G (GREEN_CATHODE)
unnamed: R14.2, RGB5.B (BLUE_CATHODE)
unnamed: R13.2, RGB5.R (RED_CATHODE)
unnamed: R25.2, RGB9.R (RED_CATHODE)
unnamed: R30.2, RGB10.G (GREEN_CATHODE)
unnamed: R29.2, RGB10.B (BLUE_CATHODE)
unnamed: R18.2, RGB6.G (GREEN_CATHODE)
unnamed: R17.2, RGB6.B (BLUE_CATHODE)
unnamed: R16.2, RGB6.R (RED_CATHODE)
unnamed: R28.2, RGB10.R (RED_CATHODE)
unnamed: R33.2, RGB11.G (GREEN_CATHODE)
unnamed: R32.2, RGB11.B (BLUE_CATHODE)
unnamed: R31.2, RGB11.R (RED_CATHODE)
unnamed: R36.2, RGB12.G (GREEN_CATHODE)
unnamed: R35.2, RGB12.B (BLUE_CATHODE)
unnamed: R34.2, RGB12.R (RED_CATHODE)
unnamed: R19.2, RGB7.R (RED_CATHODE)
unnamed: R20.2, RGB7.B (BLUE_CATHODE)
unnamed: R21.2, RGB7.G (GREEN_CATHODE)
unnamed: R22.2, RGB8.R (RED_CATHODE)
unnamed: R23.2, RGB8.B (BLUE_CATHODE)
unnamed: R24.2, RGB8.G (GREEN_CATHODE)
unnamed: R39.2, RGB13.G (GREEN_CATHODE)
unnamed: R38.2, RGB13.B (BLUE_CATHODE)
unnamed: R9.1, ULN2.18
unnamed: R10.1, ULN2.17
unnamed: R11.1, ULN2.16
unnamed: R12.1, ULN2.15
unnamed: R13.1, ULN2.14
unnamed: R14.1, ULN2.13
unnamed: R15.1, ULN2.12
unnamed: R16.1, ULN2.11
unnamed: R17.1, ULN3.18
unnamed: R18.1, ULN3.17
unnamed: R37.2, RGB13.R (RED_CATHODE)
unnamed: R42.2, RGB14.G (GREEN_CATHODE)
unnamed: R41.2, RGB14.B (BLUE_CATHODE)
unnamed: R40.2, RGB14.R (RED_CATHODE)
unnamed: R25.1, ULN4.18
unnamed: R26.1, ULN4.17
unnamed: R27.1, ULN4.16
unnamed: R28.1, ULN4.15
unnamed: R29.1, ULN4.14
unnamed: R30.1, ULN4.13
unnamed: R31.1, ULN4.12
unnamed: R32.1, ULN4.11
unnamed: R33.1, ULN5.18
unnamed: R34.1, ULN5.17
unnamed: R35.1, ULN5.16
unnamed: R36.1, ULN5.15
unnamed: R37.1, ULN5.14
unnamed: R38.1, ULN5.13
unnamed: R39.1, ULN5.12
unnamed: R40.1, ULN5.11
unnamed: R41.1, ULN6.18
unnamed: R42.1, ULN6.17
unnamed: R43.1, ULN6.16
unnamed: R44.1, ULN6.15
unnamed: R45.1, ULN6.14
unnamed: R46.1, ULN6.13
unnamed: R47.1, ULN6.12
unnamed: R48.1, ULN6.11
unnamed: R43.2, RGB15.R (RED_CATHODE)
unnamed: R44.2, RGB15.B (BLUE_CATHODE)
unnamed: R45.2, RGB15.G (GREEN_CATHODE)
unnamed: R46.2, RGB16.R (RED_CATHODE)
unnamed: R47.2, RGB16.B (BLUE_CATHODE)
unnamed: R48.2, RGB16.G (GREEN_CATHODE)
unnamed: R51.2, RGB17.G (GREEN_CATHODE)
unnamed: R50.2, RGB17.B (BLUE_CATHODE)
unnamed: R49.2, RGB17.R (RED_CATHODE)
unnamed: R54.2, RGB18.G (GREEN_CATHODE)
unnamed: R53.2, RGB18.B (BLUE_CATHODE)
unnamed: R52.2, RGB18.R (RED_CATHODE)
unnamed: R57.2, RGB19.G (GREEN_CATHODE)
unnamed: R56.2, RGB19.B (BLUE_CATHODE)
unnamed: R55.2, RGB19.R (RED_CATHODE)
unnamed: R60.2, RGB20.G (GREEN_CATHODE)
unnamed: R59.2, RGB20.B (BLUE_CATHODE)
unnamed: R58.2, RGB20.R (RED_CATHODE)
unnamed: R63.2, RGB21.G (GREEN_CATHODE)
unnamed: R62.2, RGB21.B (BLUE_CATHODE)
unnamed: R61.2, RGB21.R (RED_CATHODE)
unnamed: R66.2, RGB22.G (GREEN_CATHODE)
unnamed: R65.2, RGB22.B (BLUE_CATHODE)
unnamed: R64.2, RGB22.R (RED_CATHODE)
unnamed: R49.1, ULN7.18
unnamed: R50.1, ULN7.17
unnamed: R51.1, ULN7.16
unnamed: R52.1, ULN7.15
unnamed: R53.1, ULN7.14
unnamed: R54.1, ULN7.13
unnamed: R55.1, ULN7.12
unnamed: R56.1, ULN7.11
unnamed: R57.1, ULN8.18
unnamed: R58.1, ULN8.17
unnamed: R59.1, ULN8.16
unnamed: R60.1, ULN8.15
unnamed: R61.1, ULN8.14
unnamed: R62.1, ULN8.13
unnamed: R63.1, ULN8.12
unnamed: R64.1, ULN8.11
unnamed: R65.1, ULN9.18
unnamed: R66.1, ULN9.17
unnamed: R67.1, ULN9.16
unnamed: R68.1, ULN9.15
unnamed: R69.1, ULN9.14
unnamed: R70.1, ULN9.13
unnamed: R71.1, ULN9.12
unnamed: R72.1, ULN9.11
unnamed: R67.2, RGB23.R (RED_CATHODE)
unnamed: R68.2, RGB23.B (BLUE_CATHODE)
unnamed: R69.2, RGB23.G (GREEN_CATHODE)
unnamed: R70.2, RGB24.R (RED_CATHODE)
unnamed: R71.2, RGB24.B (BLUE_CATHODE)
unnamed: R72.2, RGB24.G (GREEN_CATHODE)
unnamed: R75.2, RGB25.G (GREEN_CATHODE)
unnamed: R74.2, RGB25.B (BLUE_CATHODE)
unnamed: R73.2, RGB25.R (RED_CATHODE)
unnamed: R78.2, RGB26.G (GREEN_CATHODE)
unnamed: R77.2, RGB26.B (BLUE_CATHODE)
unnamed: R76.2, RGB26.R (RED_CATHODE)
unnamed: R81.2, RGB27.G (GREEN_CATHODE)
unnamed: R80.2, RGB27.B (BLUE_CATHODE)
unnamed: R79.2, RGB27.R (RED_CATHODE)
unnamed: R84.2, RGB28.G (GREEN_CATHODE)
unnamed: R83.2, RGB28.B (BLUE_CATHODE)
unnamed: R82.2, RGB28.R (RED_CATHODE)
unnamed: R87.2, RGB29.G (GREEN_CATHODE)
unnamed: R86.2, RGB29.B (BLUE_CATHODE)
unnamed: R85.2, RGB29.R (RED_CATHODE)
unnamed: R90.2, RGB30.G (GREEN_CATHODE)
unnamed: R89.2, RGB30.B (BLUE_CATHODE)
unnamed: R88.2, RGB30.R (RED_CATHODE)
unnamed: R73.1, ULN10.18
unnamed: R74.1, ULN10.17
unnamed: R75.1, ULN10.16
unnamed: R76.1, ULN10.15
unnamed: R77.1, ULN10.14
unnamed: R78.1, ULN10.13
unnamed: R79.1, ULN10.12
unnamed: R80.1, ULN10.11
unnamed: R81.1, ULN11.18
unnamed: R82.1, ULN11.17
unnamed: R83.1, ULN11.16
unnamed: R84.1, ULN11.15
unnamed: R85.1, ULN11.14
unnamed: R86.1, ULN11.13
unnamed: R87.1, ULN11.12
unnamed: R88.1, ULN11.11
unnamed: R89.1, ULN12.18
unnamed: R90.1, ULN12.17
unnamed: R91.1, ULN12.16
unnamed: R92.1, ULN12.15
unnamed: R93.1, ULN12.14
unnamed: R94.1, ULN12.13
unnamed: R95.1, ULN12.12
unnamed: R96.1, ULN12.11
unnamed: R91.2, RGB31.R (RED_CATHODE)
unnamed: R92.2, RGB31.B (BLUE_CATHODE)
unnamed: R93.2, RGB31.G (GREEN_CATHODE)
unnamed: R94.2, RGB32.R (RED_CATHODE)
unnamed: R95.2, RGB32.B (BLUE_CATHODE)
unnamed: R96.2, RGB32.G (GREEN_CATHODE)
unnamed: R99.2, RGB33.G (GREEN_CATHODE)
unnamed: R98.2, RGB33.B (BLUE_CATHODE)
unnamed: R97.2, RGB33.R (RED_CATHODE)
unnamed: R102.2, RGB34.G (GREEN_CATHODE)
unnamed: R101.2, RGB34.B (BLUE_CATHODE)
unnamed: R100.2, RGB34.R (RED_CATHODE)
unnamed: R105.2, RGB35.G (GREEN_CATHODE)
unnamed: R104.2, RGB35.B (BLUE_CATHODE)
unnamed: R103.2, RGB35.R (RED_CATHODE)
unnamed: R108.2, RGB36.G (GREEN_CATHODE)
unnamed: R107.2, RGB36.B (BLUE_CATHODE)
unnamed: R106.2, RGB36.R (RED_CATHODE)
unnamed: R97.1, ULN13.18
unnamed: R98.1, ULN13.17
unnamed: R99.1, ULN13.16
unnamed: R100.1, ULN13.15
unnamed: R101.1, ULN13.14
unnamed: R102.1, ULN13.13
unnamed: R103.1, ULN13.12
unnamed: R104.1, ULN13.11
unnamed: R105.1, ULN14.18
unnamed: R106.1, ULN14.17
unnamed: R107.1, ULN14.16
unnamed: R108.1, ULN14.15
R1: ULN1.1; also elsewhere on the board
R2: ULN1.4; also elsewhere on the board
R3: ULN1.7; also elsewhere on the board
R4: ULN2.2; also elsewhere on the board
R5: ULN2.5; also elsewhere on the board
R6: ULN2.8; also elsewhere on the board
R7: ULN3.3; also elsewhere on the board
R8: ULN3.6; also elsewhere on the board
R9: ULN4.1; also elsewhere on the board
R10: ULN4.4; also elsewhere on the board
R11: ULN4.7; also elsewhere on the board
R12: ULN5.2; also elsewhere on the board
R13: ULN5.5; also elsewhere on the board
R14: ULN5.8; also elsewhere on the board
R15: ULN6.3; also elsewhere on the board
R16: ULN6.6; also elsewhere on the board
R17: ULN7.1; also elsewhere on the board
R18: ULN7.4; also elsewhere on the board
R19: ULN7.7; also elsewhere on the board
R20: ULN8.2; also elsewhere on the board
R21: ULN8.5; also elsewhere on the board
R22: ULN8.8; also elsewhere on the board
R23: ULN9.3; also elsewhere on the board
R24: ULN9.6; also elsewhere on the board
R25: ULN10.1; also elsewhere on the board
R26: ULN10.4; also elsewhere on the board
R27: ULN10.7; also elsewhere on the board
R28: ULN11.2; also elsewhere on the board
R29: ULN11.5; also elsewhere on the board
R30: ULN11.8; also elsewhere on the board
R31: ULN12.3; also elsewhere on the board
R32: ULN12.6; also elsewhere on the board
R33: ULN13.1; also elsewhere on the board
R34: ULN13.4; also elsewhere on the board
R35: ULN13.7; also elsewhere on the board
R36: ULN14.2; also elsewhere on the board

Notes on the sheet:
Vorwiderstände: Rot: 129 Ohm -> 20 mA Grün: 144 Ohm -> 13 mA Blau: 167 Ohm -> 11 mA
armlab-ng2

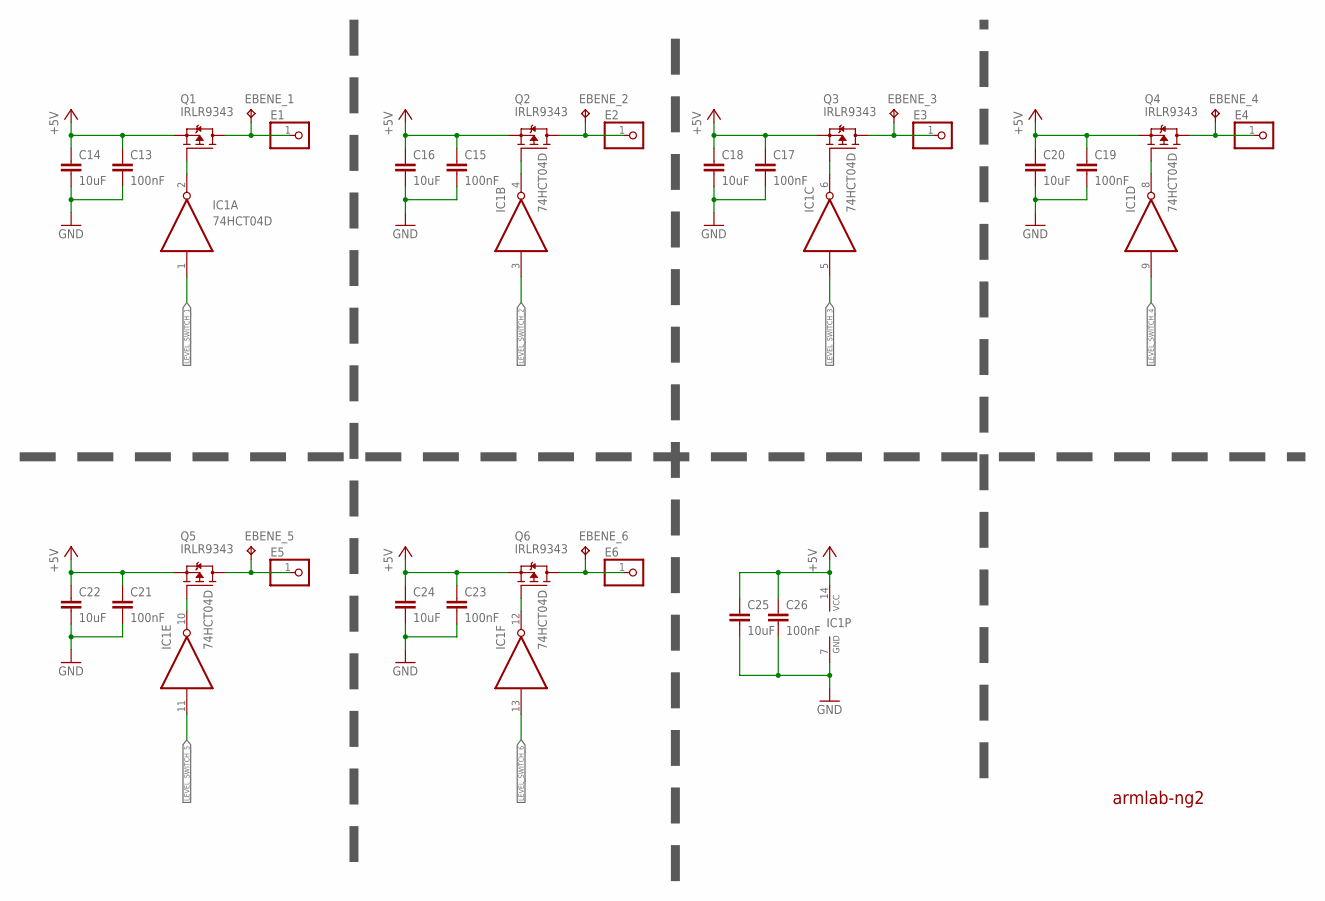
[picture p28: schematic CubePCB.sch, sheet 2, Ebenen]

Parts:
C13, C15, C17, C19, C21, C23, C26: 100nF; C0603K
C14, C16, C18, C20, C22, C24, C25: 10uF; C0603K
E1, E2, E3, E4, E5, E6: PINHD-1X1/LONG; 1X01
EBENE_1, EBENE_2, EBENE_3, EBENE_4, EBENE_5, EBENE_6: TPB1,27; B1,27
IC1: 74HCT04D; SO14
Q1, Q2, Q3, Q4, Q5, Q6: IRLR9343; TO252

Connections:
+5V: C13.1, C14.1, C15.1, C16.1, C17.1, C18.1, C19.1, C20.1, C21.1, C22.1, C23.1, C24.1, C25.1, C26.1, IC1.14 (VCC), Q1.2 (S), Q2.2 (S), Q3.2 (S), Q4.2 (S), Q5.2 (S), Q6.2 (S); also elsewhere on the board
EBENE_1: E1.1, EBENE_1.TP, Q1.3 (D)
EBENE_2: E2.1, EBENE_2.TP, Q2.3 (D)
EBENE_3: E3.1, EBENE_3.TP, Q3.3 (D)
EBENE_4: E4.1, EBENE_4.TP, Q4.3 (D)
EBENE_5: E5.1, EBENE_5.TP, Q5.3 (D)
EBENE_6: E6.1, EBENE_6.TP, Q6.3 (D)
GND: C13.2, C14.2, C15.2, C16.2, C17.2, C18.2, C19.2, C20.2, C21.2, C22.2, C23.2, C24.2, C25.2, C26.2, IC1.7 (GND); also elsewhere on the board
LEVEL_SWITCH_1: IC1.1 (I); also elsewhere on the board
LEVEL_SWITCH_2: IC1.3 (I); also elsewhere on the board
LEVEL_SWITCH_3: IC1.5 (I); also elsewhere on the board
LEVEL_SWITCH_4: IC1.9 (I); also elsewhere on the board
LEVEL_SWITCH_5: IC1.11 (I); also elsewhere on the board
LEVEL_SWITCH_6: IC1.13 (I); also elsewhere on the board
unnamed: IC1.4 (O), Q2.1 (G)
unnamed: IC1.2 (O), Q1.1 (G)
unnamed: IC1.6 (O), Q3.1 (G)
unnamed: IC1.8 (O), Q4.1 (G)
unnamed: IC1.10 (O), Q5.1 (G)
unnamed: IC1.12 (O), Q6.1 (G)

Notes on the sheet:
armlab-ng2

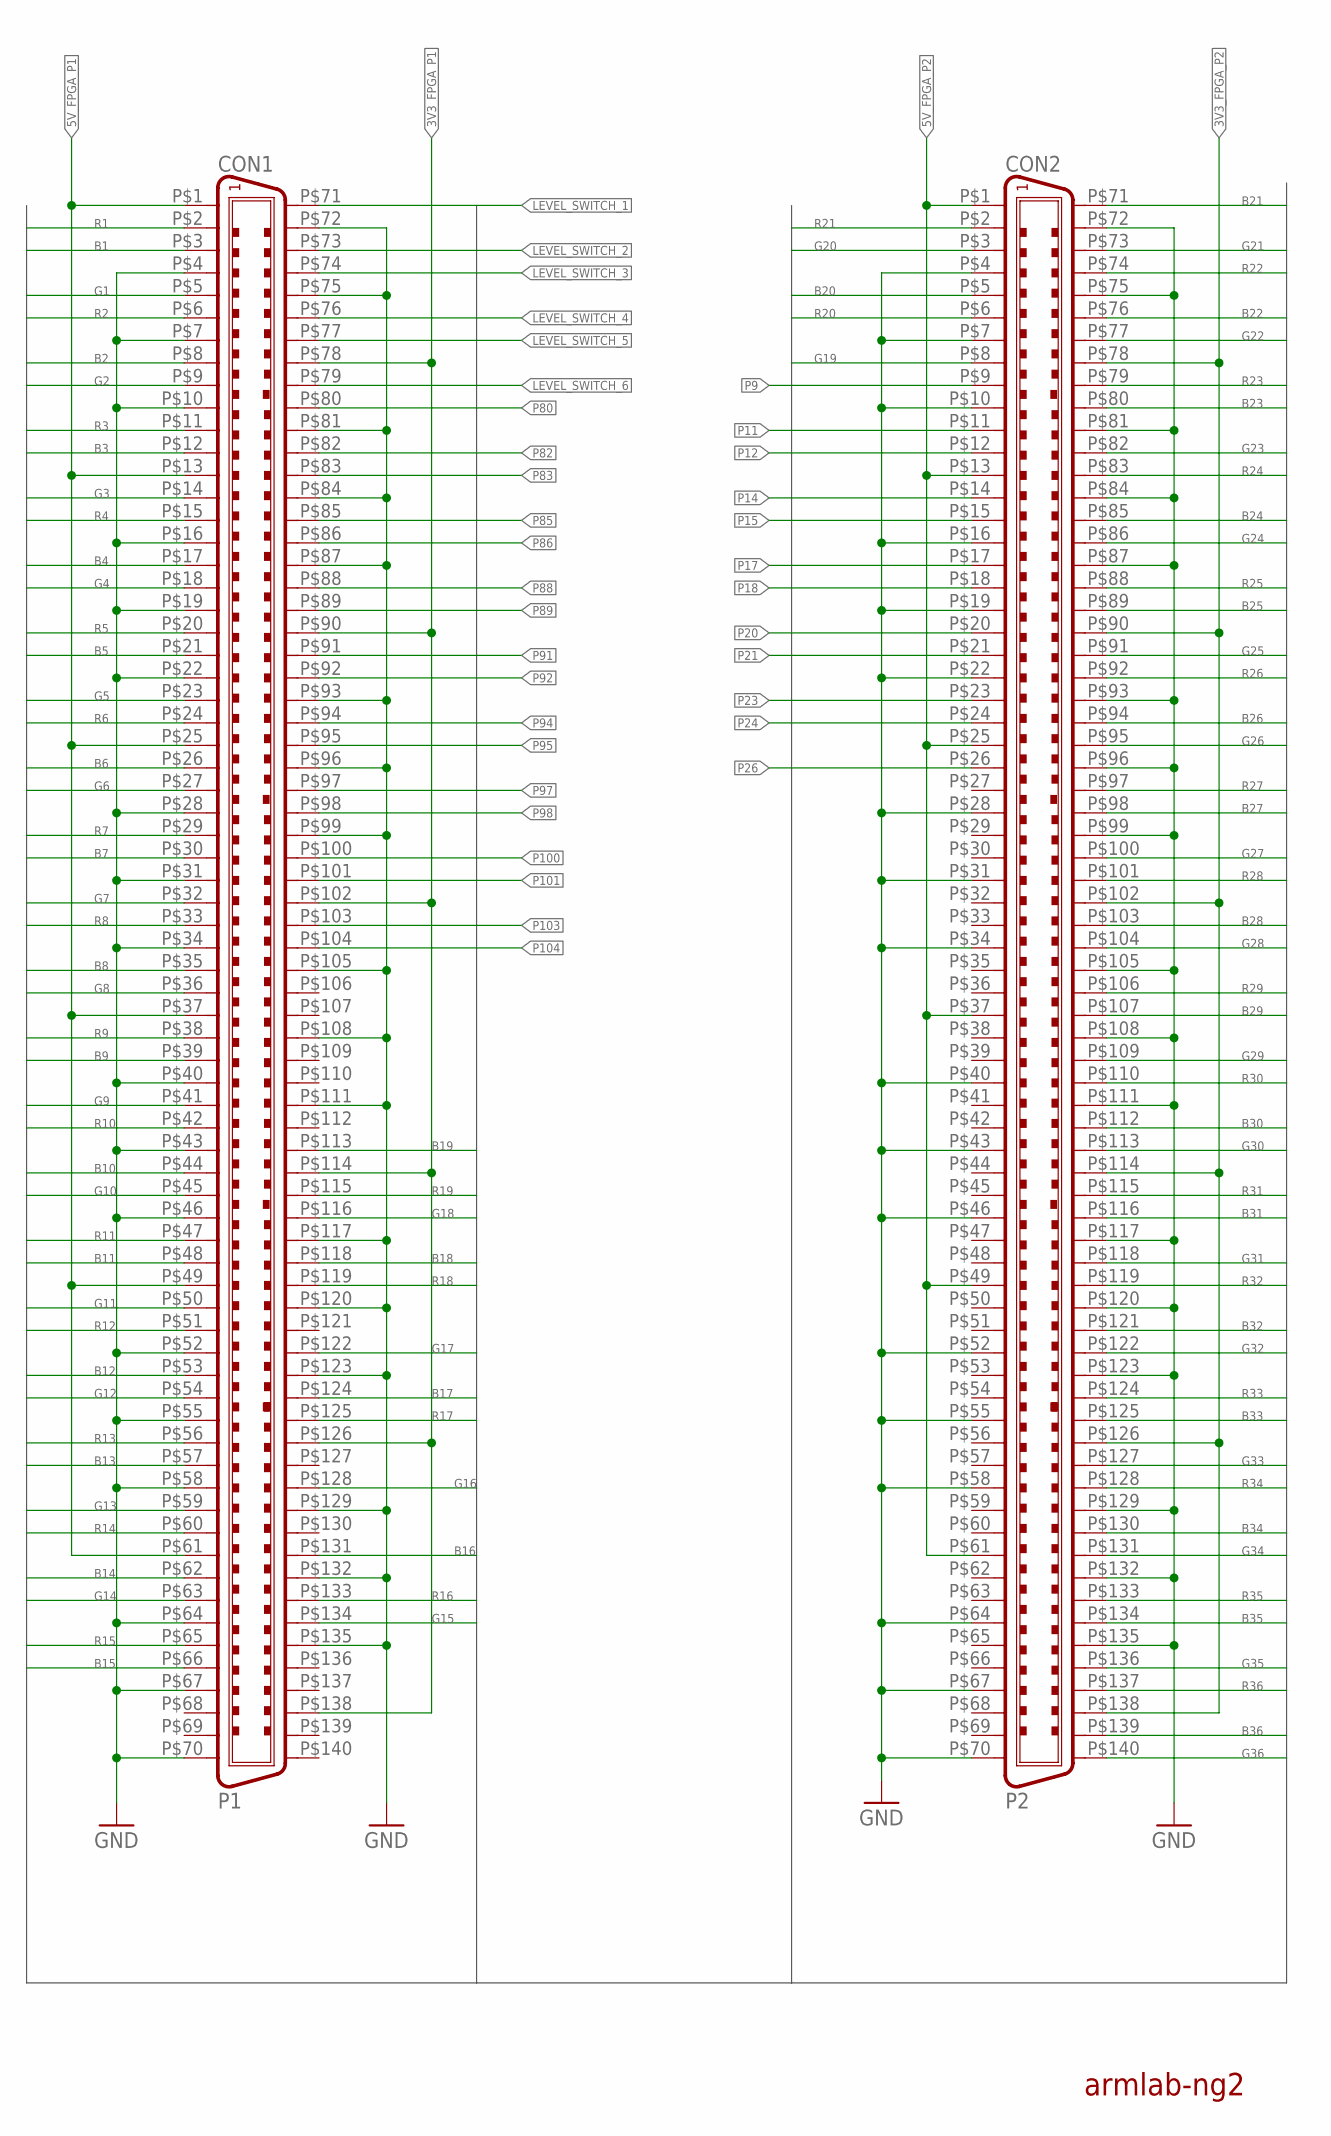
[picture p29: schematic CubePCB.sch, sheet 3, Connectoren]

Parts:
CON1: P1; 140-FH0.8
CON2: P2; 140-FH0.8

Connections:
3V3_FPGA_P1: CON1.P$78 (78), CON1.P$90 (90), CON1.P$102 (102), CON1.P$114 (114), CON1.P$126 (126), CON1.P$138 (138)
3V3_FPGA_P2: CON2.P$78 (78), CON2.P$90 (90), CON2.P$102 (102), CON2.P$114 (114), CON2.P$126 (126), CON2.P$138 (138)
5V_FPGA_P1: CON1.P$1 (1), CON1.P$13 (13), CON1.P$25 (25), CON1.P$37 (37), CON1.P$49 (49), CON1.P$61 (61)
5V_FPGA_P2: CON2.P$1 (1), CON2.P$13 (13), CON2.P$25 (25), CON2.P$37 (37), CON2.P$49 (49), CON2.P$61 (61)
B1: CON1.P$3 (3); also elsewhere on the board
B2: CON1.P$8 (8); also elsewhere on the board
B3: CON1.P$12 (12); also elsewhere on the board
B4: CON1.P$17 (17); also elsewhere on the board
B5: CON1.P$21 (21); also elsewhere on the board
B6: CON1.P$26 (26); also elsewhere on the board
B7: CON1.P$30 (30); also elsewhere on the board
B8: CON1.P$35 (35); also elsewhere on the board
B9: CON1.P$39 (39); also elsewhere on the board
B10: CON1.P$44 (44); also elsewhere on the board
B11: CON1.P$48 (48); also elsewhere on the board
B12: CON1.P$53 (53); also elsewhere on the board
B13: CON1.P$57 (57); also elsewhere on the board
B14: CON1.P$62 (62); also elsewhere on the board
B15: CON1.P$66 (66); also elsewhere on the board
B16: CON1.P$131 (131); also elsewhere on the board
B17: CON1.P$124 (124); also elsewhere on the board
B18: CON1.P$118 (118); also elsewhere on the board
B19: CON1.P$113 (113); also elsewhere on the board
B20: CON2.P$5 (5); also elsewhere on the board
B21: CON2.P$71 (71); also elsewhere on the board
B22: CON2.P$76 (76); also elsewhere on the board
B23: CON2.P$80 (80); also elsewhere on the board
B24: CON2.P$85 (85); also elsewhere on the board
B25: CON2.P$89 (89); also elsewhere on the board
B26: CON2.P$94 (94); also elsewhere on the board
B27: CON2.P$98 (98); also elsewhere on the board
B28: CON2.P$103 (103); also elsewhere on the board
B29: CON2.P$107 (107); also elsewhere on the board
B30: CON2.P$112 (112); also elsewhere on the board
B31: CON2.P$116 (116); also elsewhere on the board
B32: CON2.P$121 (121); also elsewhere on the board
B33: CON2.P$125 (125); also elsewhere on the board
B34: CON2.P$130 (130); also elsewhere on the board
B35: CON2.P$134 (134); also elsewhere on the board
B36: CON2.P$139 (139); also elsewhere on the board
G1: CON1.P$5 (5); also elsewhere on the board
G2: CON1.P$9 (9); also elsewhere on the board
G3: CON1.P$14 (14); also elsewhere on the board
G4: CON1.P$18 (18); also elsewhere on the board
G5: CON1.P$23 (23); also elsewhere on the board
G6: CON1.P$27 (27); also elsewhere on the board
G7: CON1.P$32 (32); also elsewhere on the board
G8: CON1.P$36 (36); also elsewhere on the board
G9: CON1.P$41 (41); also elsewhere on the board
G10: CON1.P$45 (45); also elsewhere on the board
G11: CON1.P$50 (50); also elsewhere on the board
G12: CON1.P$54 (54); also elsewhere on the board
G13: CON1.P$59 (59); also elsewhere on the board
G14: CON1.P$63 (63); also elsewhere on the board
G15: CON1.P$134 (134); also elsewhere on the board
G16: CON1.P$128 (128); also elsewhere on the board
G17: CON1.P$122 (122); also elsewhere on the board
G18: CON1.P$116 (116); also elsewhere on the board
G19: CON2.P$8 (8); also elsewhere on the board
G20: CON2.P$3 (3); also elsewhere on the board
G21: CON2.P$73 (73); also elsewhere on the board
G22: CON2.P$77 (77); also elsewhere on the board
G23: CON2.P$82 (82); also elsewhere on the board
G24: CON2.P$86 (86); also elsewhere on the board
G25: CON2.P$91 (91); also elsewhere on the board
G26: CON2.P$95 (95); also elsewhere on the board
G27: CON2.P$100 (100); also elsewhere on the board
G28: CON2.P$104 (104); also elsewhere on the board
G29: CON2.P$109 (109); also elsewhere on the board
G30: CON2.P$113 (113); also elsewhere on the board
G31: CON2.P$118 (118); also elsewhere on the board
G32: CON2.P$122 (122); also elsewhere on the board
G33: CON2.P$127 (127); also elsewhere on the board
G34: CON2.P$131 (131); also elsewhere on the board
G35: CON2.P$136 (136); also elsewhere on the board
G36: CON2.P$140 (140); also elsewhere on the board
GND: CON1.P$4 (4), CON1.P$7 (7), CON1.P$10 (10), CON1.P$16 (16), CON1.P$19 (19), CON1.P$22 (22), CON1.P$28 (28), CON1.P$31 (31), CON1.P$34 (34), CON1.P$40 (40), CON1.P$43 (43), CON1.P$46 (46), CON1.P$52 (52), CON1.P$55 (55), CON1.P$58 (58), CON1.P$64 (64), CON1.P$67 (67), CON1.P$70 (70), CON1.P$72 (72), CON1.P$75 (75), CON1.P$81 (81), CON1.P$84 (84), CON1.P$87 (87), CON1.P$93 (93), CON1.P$96 (96), CON1.P$99 (99), CON1.P$105 (105), CON1.P$108 (108), CON1.P$111 (111), CON1.P$117 (117), CON1.P$120 (120), CON1.P$123 (123), CON1.P$129 (129), CON1.P$132 (132), CON1.P$135 (135), CON2.P$4 (4), CON2.P$7 (7), CON2.P$10 (10), CON2.P$16 (16), CON2.P$19 (19), CON2.P$22 (22), CON2.P$28 (28), CON2.P$31 (31), CON2.P$34 (34), CON2.P$40 (40), CON2.P$43 (43), CON2.P$46 (46), CON2.P$52 (52), CON2.P$55 (55), CON2.P$58 (58), CON2.P$64 (64), CON2.P$67 (67), CON2.P$70 (70), CON2.P$72 (72), CON2.P$75 (75), CON2.P$81 (81), CON2.P$84 (84), CON2.P$87 (87), CON2.P$93 (93), CON2.P$96 (96), CON2.P$99 (99), CON2.P$105 (105), CON2.P$108 (108), CON2.P$111 (111), CON2.P$117 (117), CON2.P$120 (120), CON2.P$123 (123), CON2.P$129 (129), CON2.P$132 (132), CON2.P$135 (135); also elsewhere on the board
LEVEL_SWITCH_1: CON1.P$71 (71); also elsewhere on the board
LEVEL_SWITCH_2: CON1.P$73 (73); also elsewhere on the board
LEVEL_SWITCH_3: CON1.P$74 (74); also elsewhere on the board
LEVEL_SWITCH_4: CON1.P$76 (76); also elsewhere on the board
LEVEL_SWITCH_5: CON1.P$77 (77); also elsewhere on the board
LEVEL_SWITCH_6: CON1.P$79 (79); also elsewhere on the board
P9: CON2.P$9 (9)
P11: CON2.P$11 (11)
P12: CON2.P$12 (12)
P14: CON2.P$14 (14)
P15: CON2.P$15 (15)
P17: CON2.P$17 (17)
P18: CON2.P$18 (18)
P20: CON2.P$20 (20)
P21: CON2.P$21 (21)
P23: CON2.P$23 (23)
P24: CON2.P$24 (24)
P26: CON2.P$26 (26)
P80: CON1.P$80 (80)
P82: CON1.P$82 (82)
P83: CON1.P$83 (83)
P85: CON1.P$85 (85)
P86: CON1.P$86 (86)
P88: CON1.P$88 (88)
P89: CON1.P$89 (89)
P91: CON1.P$91 (91)
P92: CON1.P$92 (92)
P94: CON1.P$94 (94)
P95: CON1.P$95 (95)
P97: CON1.P$97 (97)
P98: CON1.P$98 (98)
P100: CON1.P$100 (100)
P101: CON1.P$101 (101)
P103: CON1.P$103 (103)
P104: CON1.P$104 (104)
R1: CON1.P$2 (2); also elsewhere on the board
R2: CON1.P$6 (6); also elsewhere on the board
R3: CON1.P$11 (11); also elsewhere on the board
R4: CON1.P$15 (15); also elsewhere on the board
R5: CON1.P$20 (20); also elsewhere on the board
R6: CON1.P$24 (24); also elsewhere on the board
R7: CON1.P$29 (29); also elsewhere on the board
R8: CON1.P$33 (33); also elsewhere on the board
R9: CON1.P$38 (38); also elsewhere on the board
R10: CON1.P$42 (42); also elsewhere on the board
R11: CON1.P$47 (47); also elsewhere on the board
R12: CON1.P$51 (51); also elsewhere on the board
R13: CON1.P$56 (56); also elsewhere on the board
R14: CON1.P$60 (60); also elsewhere on the board
R15: CON1.P$65 (65); also elsewhere on the board
R16: CON1.P$133 (133); also elsewhere on the board
R17: CON1.P$125 (125); also elsewhere on the board
R18: CON1.P$119 (119); also elsewhere on the board
R19: CON1.P$115 (115); also elsewhere on the board
R20: CON2.P$6 (6); also elsewhere on the board
R21: CON2.P$2 (2); also elsewhere on the board
R22: CON2.P$74 (74); also elsewhere on the board
R23: CON2.P$79 (79); also elsewhere on the board
R24: CON2.P$83 (83); also elsewhere on the board
R25: CON2.P$88 (88); also elsewhere on the board
R26: CON2.P$92 (92); also elsewhere on the board
R27: CON2.P$97 (97); also elsewhere on the board
R28: CON2.P$101 (101); also elsewhere on the board
R29: CON2.P$106 (106); also elsewhere on the board
R30: CON2.P$110 (110); also elsewhere on the board
R31: CON2.P$115 (115); also elsewhere on the board
R32: CON2.P$119 (119); also elsewhere on the board
R33: CON2.P$124 (124); also elsewhere on the board
R34: CON2.P$128 (128); also elsewhere on the board
R35: CON2.P$133 (133); also elsewhere on the board
R36: CON2.P$137 (137); also elsewhere on the board

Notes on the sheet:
armlab-ng2

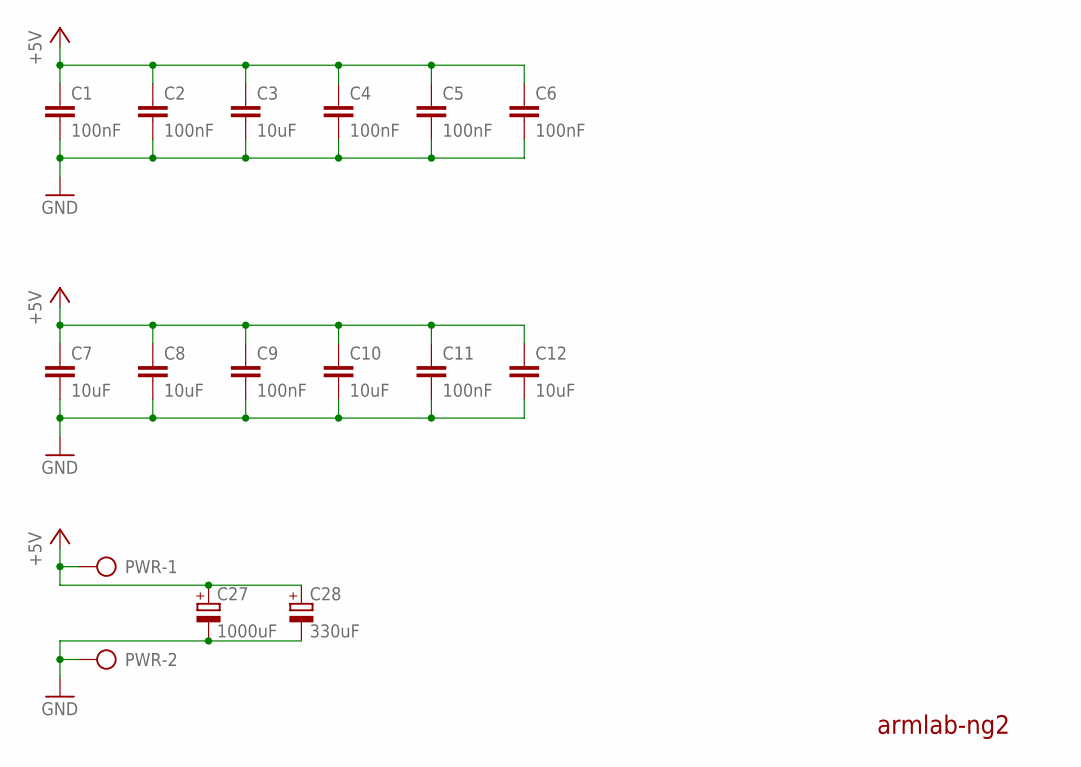
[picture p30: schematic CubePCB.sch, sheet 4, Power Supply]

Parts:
C1, C2, C4, C5, C6, C9, C11: 100nF; C0603K
C3, C7, C8, C10, C12: 10uF; C0603K
C27: 1000uF; E5-10,5
C28: 330uF; E3,5-8
PWR: AK500/2

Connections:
+5V: C1.1, C2.1, C3.1, C4.1, C5.1, C6.1, C7.1, C8.1, C9.1, C10.1, C11.1, C12.1, C27.+, C28.+, PWR.1; also elsewhere on the board
GND: C1.2, C2.2, C3.2, C4.2, C5.2, C6.2, C7.2, C8.2, C9.2, C10.2, C11.2, C12.2, C27.-, C28.-, PWR.2; also elsewhere on the board

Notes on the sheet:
armlab-ng2

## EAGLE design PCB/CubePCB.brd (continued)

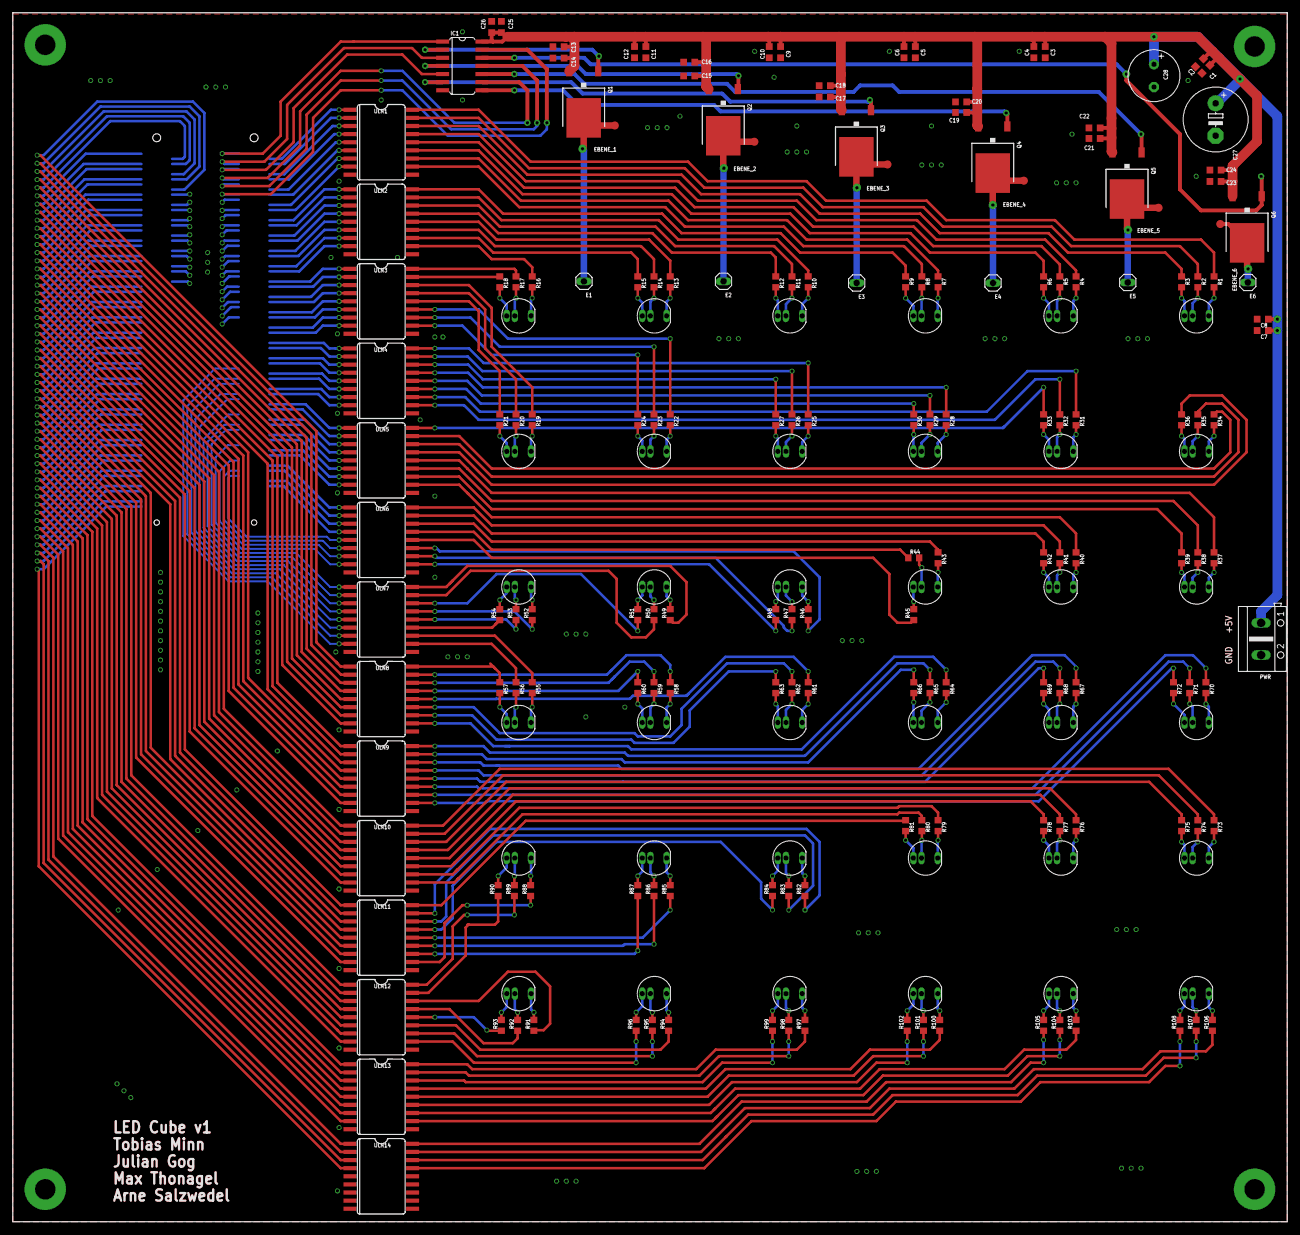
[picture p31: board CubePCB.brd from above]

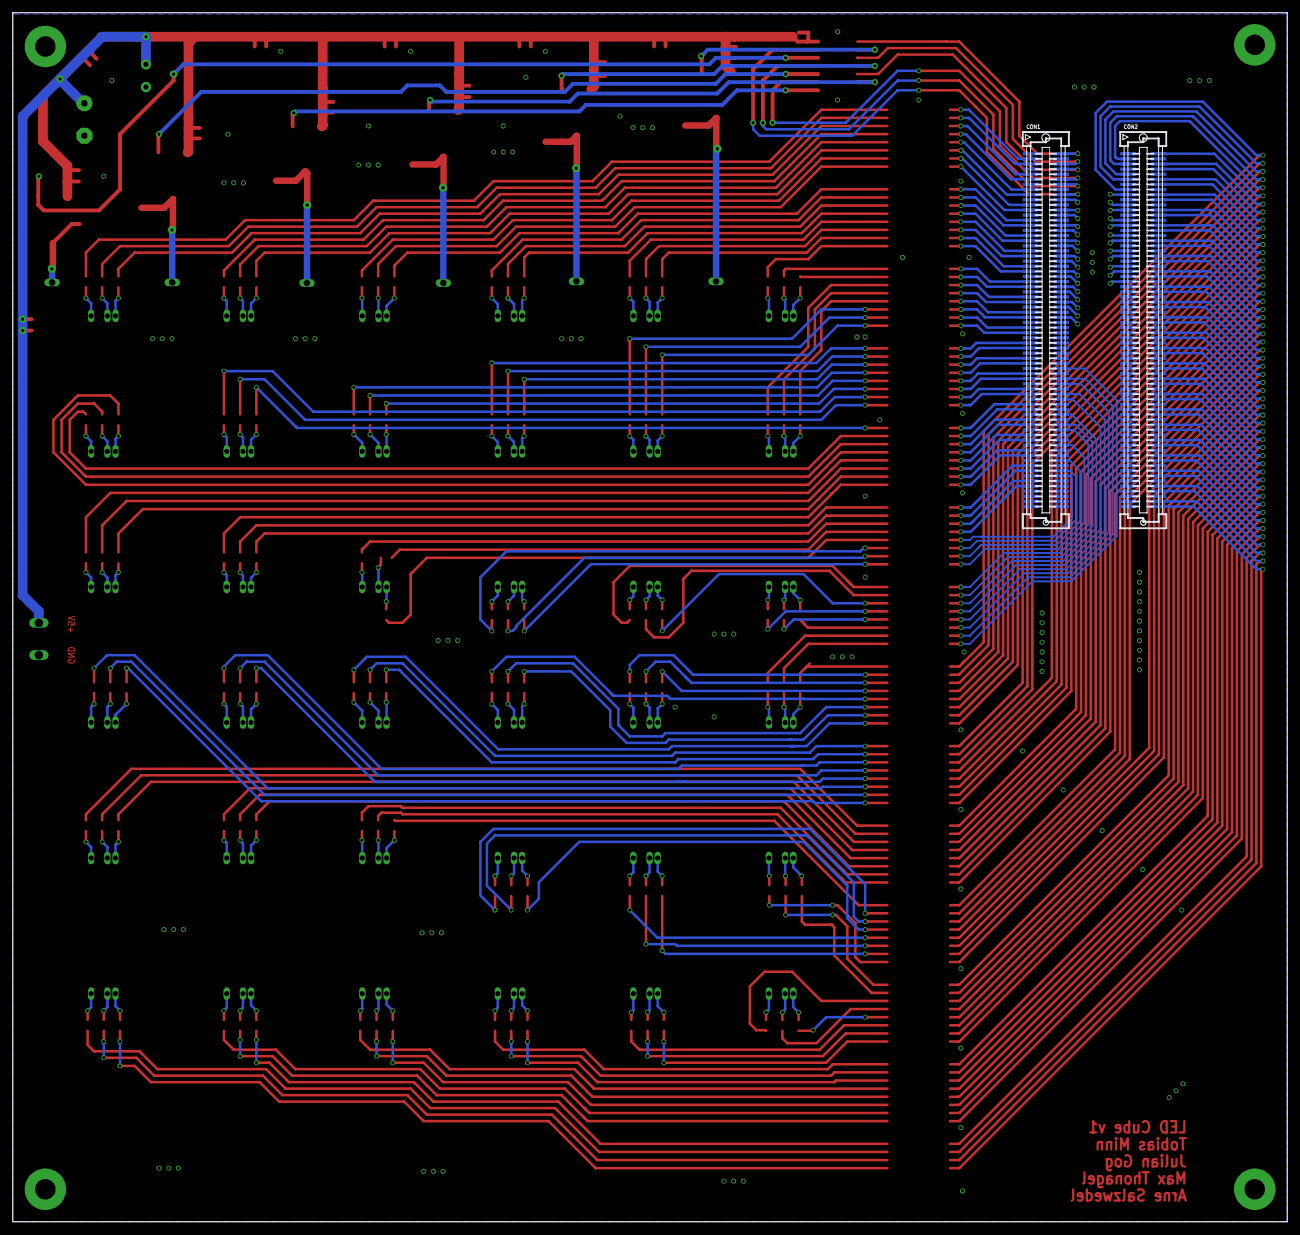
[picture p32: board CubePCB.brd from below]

Board: 2 copper layers, 199.4 x 189.2 mm, 208 parts (2 on the bottom side), 348 nets.

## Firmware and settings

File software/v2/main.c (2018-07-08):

#include <gtk/gtk.h>
#include <stdint.h>
#include <time.h>
#include <math.h>
#include <stdlib.h>

#include <sys/types.h>
#include <ifaddrs.h>

#include "cube.h"

#define CUBE_DIM    6

void *cubeSim(void*);
GtkBuilder* builder; 
GtkWidget* interfaceSelectBox;
GtkListStore* liststore;
 
int main(int argc, char *argv[])
{
    
    GtkWidget* window;

    pthread_mutex_init (&ledCubeMutex, NULL);
    pthread_mutex_init (&etherFrameMutex, NULL);

    showLedCube = &ledCube0;
	drawLedCube = &ledCube1;

	sendBuf = etherFrameBuff0;
	sendMsg = etherFrameBuff1;


    pthread_t cubeAnimatorThread;
    if(pthread_create(&cubeAnimatorThread, NULL, cubeAnimator, NULL)) {
        perror("creating cubeAnimator thread failed!");
        return 1;
    }

    pthread_t cubePWMcontrolThread;
    if(pthread_create(&cubePWMcontrolThread, NULL, cubePWMController, NULL)) {
        perror("creating cubePWMController thread failed!");
        return 1;
    }

    pthread_t senderThread;
    if(pthread_create(&senderThread, NULL, ethSend, NULL)) {
        perror("creating sender thread failed!");
        return 1;
    }

    gtk_init(&argc, &argv);
 
    builder = gtk_builder_new();
    gtk_builder_add_from_file (builder, "gui.glade", NULL);
 
    window = GTK_WIDGET(gtk_builder_get_object(builder, "mainWindow"));
    gtk_builder_connect_signals(builder, NULL);

   
    //fill interface combo box
    liststore = (GtkListStore*)gtk_builder_get_object(builder, "interfaceListStore");

    struct ifaddrs *addrs,*tmp;

    getifaddrs(&addrs);
    tmp = addrs;

    while (tmp)
    {
    	if (tmp->ifa_addr && tmp->ifa_addr->sa_family == AF_PACKET) {
    		if (tmp->ifa_name[0] != 'l' && tmp->ifa_name[1] != '0' && tmp->ifa_name[2] != '\0'){
    			gtk_list_store_insert_with_values(liststore, NULL, -1, 0, tmp->ifa_name, -1);
    		}
    	}

    	tmp = tmp->ifa_next;
    }

    freeifaddrs(addrs);


    interfaceSelectBox = GTK_WIDGET(gtk_builder_get_object(builder, "interfaceSelectBox"));

    GtkTreeIter iter;
    gtk_tree_model_iter_nth_child ((GtkTreeModel*)liststore, &iter, NULL, 0);
    gtk_combo_box_set_active_iter((GtkComboBox*)interfaceSelectBox, &iter);

    gtk_widget_show(window);   

    srand(time(NULL)); 
   
    pthread_t cubeSimThread;
    if(pthread_create(&cubeSimThread, NULL, cubeSim, NULL)) {
        perror("creating cube sim thread failed!");
        return 1;
    }

             
    gtk_main();

    g_object_unref(builder);

 
    return 0;
}


void *cubeSim(void* void_ptr) {

    GtkWidget *cubeSim;
    cubeSim = GTK_WIDGET(gtk_builder_get_object(builder, "cubeSim"));

    while(1) {
        gtk_widget_queue_draw(cubeSim);
        usleep(20000);
    }

}

void selectBoxChanged_cb()
{
	printf("combo changed\n");

	GtkTreeIter iter;
	gtk_combo_box_get_active_iter((GtkComboBox*)interfaceSelectBox, &iter);
	gchar* ifName;
	gtk_tree_model_get((GtkTreeModel*)liststore, &iter, 0, &ifName, -1);
	initEthernet(ifName);
}


void btnMode1_clicked_cb()
{
    printf("btn1 pressed\n");
    cubeSetAnimationMode(1);
}

void btnMode2_clicked_cb()
{
    printf("btn2 pressed\n");
    cubeSetAnimationMode(2);
}

void btnMode3_clicked_cb()
{
    printf("btn3 pressed\n");
    cubeSetAnimationMode(3);
}

void btnMode4_clicked_cb()
{
    printf("btn4 pressed\n");
    cubeSetAnimationMode(4);
}

void btnMode5_clicked_cb()
{
    printf("btn5 pressed\n");
    cubeSetAnimationMode(5);
}

void btnOff_clicked_cb()
{
    printf("btnOff pressed\n");
    cubeSetAnimationMode(0);
}
 

void main_destroy()
{
    gtk_main_quit();
}

gboolean draw_callback (GtkWidget *widget, cairo_t *cr, gpointer data)
{
  guint width, height;
  //GdkRGBA color;

  width = gtk_widget_get_allocated_width (widget);
  height = gtk_widget_get_allocated_height (widget);

  double spacing = width / (CUBE_DIM + 2);
  double ledSize = spacing * 0.09;

  cairo_set_source_rgba (cr, 0.2, 0.2, 0.2, 1);
  cairo_rectangle (cr, 0, 0, width, height);
  cairo_fill (cr);

  cairo_set_source_rgba (cr, 1, 0, 0, 1);

  for (int y = 0; y < CUBE_DIM; y++) {

    double yOffset = y * ledSize * 1.8;

    for (uint8_t x = 0; x < CUBE_DIM; x++) {
        for (uint8_t z = 0; z < CUBE_DIM; z++) {

           double r = (*showLedCube)[x][y][z].r / 255.0;
           double g = (*showLedCube)[x][y][z].g / 255.0;
           double b = (*showLedCube)[x][y][z].b / 255.0;
           
           cairo_set_source_rgba (cr, r, g, b, 1);
           cairo_arc (cr, (spacing*(x+1))+yOffset, (spacing*((CUBE_DIM-1-z)+1.8))-(yOffset*0.7), ledSize, 0, 2 * G_PI);
           cairo_fill (cr);
       }
   }
}


return FALSE;
}

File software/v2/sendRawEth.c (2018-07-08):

#include <arpa/inet.h>
#include <linux/if_packet.h>
#include <stdio.h>
#include <string.h>
#include <stdlib.h>
#include <sys/ioctl.h>
#include <sys/socket.h>
#include <net/if.h>
#include <netinet/ether.h>
#include <time.h>
#include <unistd.h>
#include <pthread.h>
#include <math.h>

#define FPGA_MAC_ADDR0	0x4c
#define FPGA_MAC_ADDR1	0xcc
#define FPGA_MAC_ADDR2	0x6a
#define FPGA_MAC_ADDR3	0xf9
#define FPGA_MAC_ADDR4	0x6e
#define FPGA_MAC_ADDR5	0xcf

#define INTERFACE	"enp0s3"
#define BUF_SIZ		122

#define BUF_PAYLOAD_BEGIN	14
#define CUBE_DIM	6

#define PWM_STEPS	256


int sockfd;
struct ifreq if_idx;
struct ifreq if_mac;
int tx_len = 0;
char sendbuf[BUF_SIZ];
struct ether_header *eh = (struct ether_header *) sendbuf;
struct sockaddr_ll socket_address;
char ifName[] = INTERFACE;

void initEthernet();
void *ethSend(void *);

typedef struct {
	uint8_t r;
	uint8_t g;
	uint8_t b;
} led;

led red = {255,0,0};
led green = {0,255,0};
led blue = {0,0,255};

led yellow = {255,255,0};
led magenta = {255,0,255};
led cyan = {0,255,255};

led white = {255,255,255};
led black = {0,0,0};

led ledCube[CUBE_DIM][CUBE_DIM][CUBE_DIM];


void drawLine(uint8_t x0, uint8_t y0, uint8_t z0, uint8_t x1, uint8_t y1, uint8_t z1, led color);
void drawCuboid(uint8_t x0, uint8_t y0, uint8_t z0, uint8_t x1, uint8_t y1, uint8_t z1, led color);
void send_single_test_frame();
void *ethSend_single(void* void_ptr);


void drawLine(uint8_t x0, uint8_t y0, uint8_t z0, uint8_t x1, uint8_t y1, uint8_t z1, led color) {
	
	if (x0 > x1) {
		uint8_t c = x0;
		x0 = x1;
		x1 = c;
	}
	if (y0 > y1) {
		uint8_t c = y0;
		y0 = y1;
		y1 = c;
	}
	if (z0 > z1) {
		uint8_t c = z0;
		z0 = z1;
		z1 = c;
	}

	uint8_t diffX = x1-x0;
	uint8_t diffY = y1-y0;
	uint8_t diffZ = z1-z0;

	for (uint8_t x = x0; x < x1; x++) {
		uint8_t y = round(((double)diffY / (double)diffX) * x + x0);
		uint8_t z = round(((double)diffZ / (double)diffX) * x + x0);

		ledCube[x][y][z] = color;
	}
}

void drawCuboid(uint8_t x0, uint8_t y0, uint8_t z0, uint8_t x1, uint8_t y1, uint8_t z1, led color) {

	for (uint8_t x = x0; x < x1; x++) {
		for (int y = y0; y < y1; y++) {
			for (int z = z0; z < z1; z++) {
				ledCube[x][y][z] = color;
			}
		}
	}
	
}

int main(int argc, char *argv[])
{
	
	srand(time(NULL)); 

    /*
    for (int c = 14; c < 95; c++) {
        sendbuf[c] = rand();
    }*/

    initEthernet();

    pthread_t senderThread;

	/* Original    
	if(pthread_create(&senderThread, NULL, ethSend, NULL)) {
		perror("creating sender thread failed!");
		return 1;
	}
	*/

	send_single_test_frame();


	// Send single Frame
	if(pthread_create(&senderThread, NULL, ethSend_single, NULL)) {
		perror("creating sender thread failed!");
		return 1;
	}

	// trap program here
	while(1){};


	led darkred = {128,0,0};

	//drawLine(0,0,0,1,CUBE_DIM,1, white);
	drawCuboid(0, 0, 0, CUBE_DIM, CUBE_DIM, CUBE_DIM, darkred);

	
	while(1) {

		for (uint8_t t = 0; t < (PWM_STEPS-1); t++) {

			for (int z = 0; z < CUBE_DIM; z++) {

				uint8_t zByteOffset = z * 18;	
					
				for (int xy = 0; xy < (CUBE_DIM*CUBE_DIM/2); xy++) {

					uint8_t x = (xy % 3)*2;
					uint8_t y = xy / 3;

					uint8_t msgByte = ledCube[x][y][z].r > t;
					msgByte |= (ledCube[x][y][z].g > t) << 1;
					msgByte |= (ledCube[x][y][z].b > t) << 2;

					msgByte |= (ledCube[x+1][y][z].r > t) << 4;
					msgByte |= (ledCube[x+1][y][z].g > t) << 5;
					msgByte |= (ledCube[x+1][y][z].b > t) << 6;

					sendbuf[BUF_PAYLOAD_BEGIN + xy + zByteOffset] = msgByte;
					
				}
			}

			usleep(19);
		}

		/*
		for (int c = BUF_PAYLOAD_BEGIN; c < BUF_SIZ; c++) {
			sendbuf[c] = 'A';
			usleep(1);
		}

		for (int c = BUF_PAYLOAD_BEGIN; c < BUF_SIZ; c++) {
			sendbuf[c] = 'B';
			usleep(1);
		}*/
	}


	pthread_join(senderThread, NULL);

	return 0;
}


void *ethSend(void* void_ptr) {

    clock_t lastsend;
    clock_t current;
    clock_t diff;

    lastsend = clock();

 
    while (1){
    for (int i=0; i<1000; i++) {

        /*
        for (int c = 14; c < 122; c++) {
            sendbuf[c] = rand();
        }*/

        //while((clock()-lastsend) < 960){};

        //while(clock()%100){};

	    sendto(sockfd, sendbuf, tx_len, 0, (struct sockaddr*)&socket_address, sizeof(struct sockaddr_ll));
        //pack++;
 
        //usleep(1000);
        /*current = clock();
        diff = current-lastsend;
        if (diff < 50)
            usleep(50 - diff);
        lastsend = current;*/

    }

    current = clock();
    diff = current-lastsend;
    lastsend = current;

    if (diff > 45000)
        printf("\033[31m %u \n", diff);
    else if (diff < 15000)
        printf("\033[33m %u \n", diff);
    else 
        printf("\033[m %u \n", diff);
    //printf("%u %u \n", diff, pack);

    
    }
}



void initEthernet() {

	/* Open RAW socket to send on */
	if ((sockfd = socket(AF_PACKET, SOCK_RAW, IPPROTO_RAW)) == -1) {
	    perror("socket");
	}

	/* Get the index of the interface to send on */
	memset(&if_idx, 0, sizeof(struct ifreq));
	strncpy(if_idx.ifr_name, ifName, IFNAMSIZ-1);
	if (ioctl(sockfd, SIOCGIFINDEX, &if_idx) < 0)
	    perror("SIOCGIFINDEX");
	/* Get the MAC address of the interface to send on */
	memset(&if_mac, 0, sizeof(struct ifreq));
	strncpy(if_mac.ifr_name, ifName, IFNAMSIZ-1);
	if (ioctl(sockfd, SIOCGIFHWADDR, &if_mac) < 0)
	    perror("SIOCGIFHWADDR");

    // Construct the Ethernet header 
	memset(sendbuf, 0, BUF_SIZ);

	/* Ethernet header */
	eh->ether_shost[0] = ((uint8_t *)&if_mac.ifr_hwaddr.sa_data)[0];
	eh->ether_shost[1] = ((uint8_t *)&if_mac.ifr_hwaddr.sa_data)[1];
	eh->ether_shost[2] = ((uint8_t *)&if_mac.ifr_hwaddr.sa_data)[2];
	eh->ether_shost[3] = ((uint8_t *)&if_mac.ifr_hwaddr.sa_data)[3];
	eh->ether_shost[4] = ((uint8_t *)&if_mac.ifr_hwaddr.sa_data)[4];
	eh->ether_shost[5] = ((uint8_t *)&if_mac.ifr_hwaddr.sa_data)[5];
	eh->ether_dhost[0] = FPGA_MAC_ADDR0;
	eh->ether_dhost[1] = FPGA_MAC_ADDR1;
	eh->ether_dhost[2] = FPGA_MAC_ADDR2;
	eh->ether_dhost[3] = FPGA_MAC_ADDR3;
	eh->ether_dhost[4] = FPGA_MAC_ADDR4;
	eh->ether_dhost[5] = FPGA_MAC_ADDR5;
	/* Ethertype field */
	eh->ether_type = htons(0x006c);//ETH_P_IP
	tx_len += sizeof(struct ether_header);

    
	/* Index of the network device */
	socket_address.sll_ifindex = if_idx.ifr_ifindex;
	/* Address length*/
	socket_address.sll_halen = ETH_ALEN;
	/* Destination MAC */
	socket_address.sll_addr[0] = FPGA_MAC_ADDR0;
	socket_address.sll_addr[1] = FPGA_MAC_ADDR1;
	socket_address.sll_addr[2] = FPGA_MAC_ADDR2;
	socket_address.sll_addr[3] = FPGA_MAC_ADDR3;
	socket_address.sll_addr[4] = FPGA_MAC_ADDR4;
	socket_address.sll_addr[5] = FPGA_MAC_ADDR5;

    //tx_len += 81;
    tx_len += 108;
}
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

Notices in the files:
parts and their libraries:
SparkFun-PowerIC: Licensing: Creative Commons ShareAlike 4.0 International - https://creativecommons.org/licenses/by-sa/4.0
